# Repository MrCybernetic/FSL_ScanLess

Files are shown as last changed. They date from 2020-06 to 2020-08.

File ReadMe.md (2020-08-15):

Feel free to join the chat / N'hésite pas à venir discuter : 



# SCANLESS
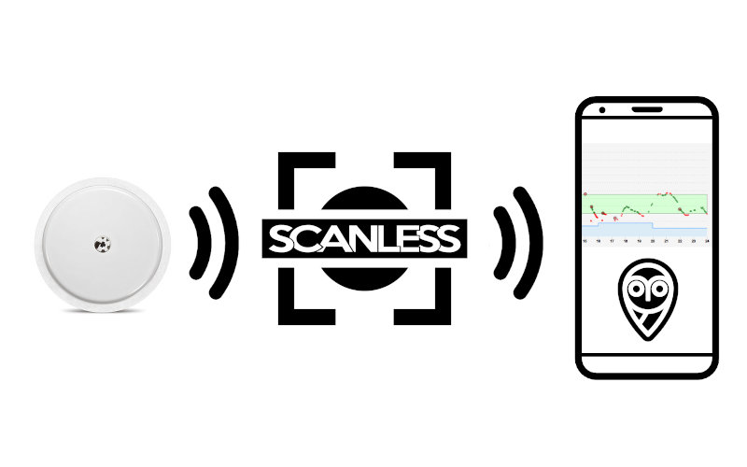
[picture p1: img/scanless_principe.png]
XDrip Principe
 

EN Flag EN

Designing an open source PCB to turn your Freestyle Libre into a wireless CGM (continuous glucose monitor) based on LimiTTer ([Limitter Original Project](https://github.com/JoernL/LimiTTer)). Hardware inside :
+ BM019 NFC tag reader ([BM019 from Solutions Cubed](http://www.solutions-cubed.com/bm019/), see BM019 folder to see documentation and schematics)
+ HM17 BLE Module
+ Atmega328P (Arduino Pro Mini compatible)
+ USB to Serial Converter to program the Arduino (CP2104)
+ LiPo Charger (MCP73831)
+ LiPo Battery (3.7V)

SCANLESS is an open source Project NOT maintained by Abbott. It is a experimental DIY project. You can contribute in this project as you want.

## Project Progress

+ BM019 tested  :heavy_check_mark: 
+ Electronics : Schematics and PCB reviewed :heavy_check_mark: 
+ BLE to test :heavy_check_mark:
+ Arduino to test ([Keencave Github / LBridge Arduino Code](https://github.com/keencave/LBridge)) :heavy_check_mark:
+ XDrip to test :heavy_check_mark:
+ Design 3D printable enclosure :heavy_check_mark:

--- 

FR Flag FR

Le but de ce projet est de concevoir un PCB en open source pour suivre votre glycémie via votre smartphone. Ce projet est basé sur celui-ci : LimiTTer ([JoernL Github / Projet Original Limitter](https://github.com/JoernL/LimiTTer)).
+ Lecteur de tag NFC BM019 ([BM019 de Solutions Cubed](http://www.solutions-cubed.com/bm019/), la doc du BM019 et son schéma est dans le dossier BM019)
+ module BLE HM17
+ Atmega328P (Compatible avec Arduino Pro Mini bootloader)
+ Convertisseur USB vers Série pour pouvoir programmer l'Arduino (CP2104)
+ circuit intégré pour charger la LiPo (MCP73831)
+ une batterie LiPo (3.7V, ???mAh pas encore définie)

SCANLESS est un projet open source non supporté par Abbott. C'est un projet DIY expérimental. N'hésitez surtout pas à proposer des améliorations.

# Avancement

+ Tester le fonctionnement du BM019 :heavy_check_mark:
+ Vérification des schémas électronique :heavy_check_mark: 
+ Tester le BLE :heavy_check_mark:
+ Tester le code Arduino ([Keencave Github / LBridge Arduino Code](https://github.com/keencave/LBridge)) :heavy_check_mark:
+ Tester l'appli XDrip :heavy_check_mark:
+ Concevoir une coque imprimable (3D) :heavy_check_mark:

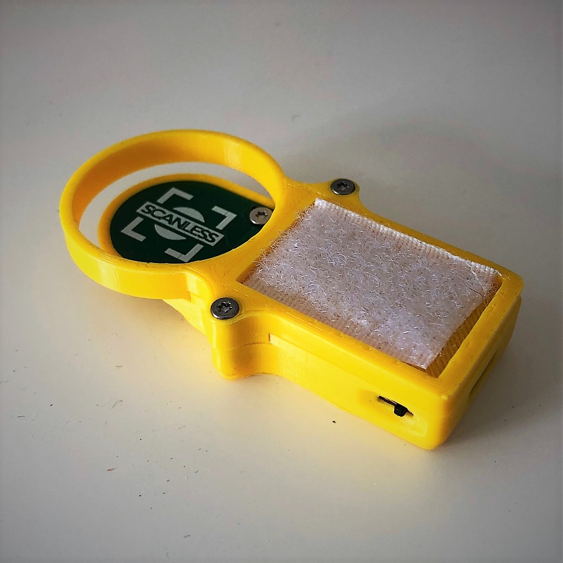
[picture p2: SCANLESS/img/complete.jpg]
PCB


*Actual state / état actuel*

# **#WeAreNotWaiting**

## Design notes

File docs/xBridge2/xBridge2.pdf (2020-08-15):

### XBridge2 - v2.48b (Use only with xDrip+)

XBridge2 is firmware code for a Pololu Wixel, and additional circuitry, that can make the wixel act as a bridge between a Dexcom G4 Transmitter and a smart phone using Bluetooth 4.0 (BLE) with HM-10/11 modules, or Bluetooth 4.1 with HM-16/17 modules. It requires that the Wixel be connected to a HM-1x BLE module, using the design originally put together by Stephen Black for his XDrip system as a minimum. There is a minor hardware modification required in order to receive the bridge battery voltage for monitoring in the app, and a modification to the wiring that allows the HM-1x to be powered down with the wixel low power mode, and powered up when the wixel wakes. Please see the Circuit diagrams below.

V2.48b adds support for packet caching, thanks to @savek-cc. This means that the bridge can store up to 5 hours of captured packets, and allows you to walk away from your phone running xDrip+. When you come back in range of the phone, and the next packet from the Dexcom transmitter is received, all of the saved packets will be sent to xDrip+.

NOTE: This wixel app can be used with a classic xDrip-wixel wiring, but you will not have the full battery saving features the code can provide. The xBridge2 code will automatically detect if you are using a classic xDrip-wixel circuit, and automatically detect your HM-1x module baud rate.

Acknowledgements
The original code, engineering and decoding of the Dexcom data packet was done by Adrien de Croy, whithout whom this project would not be possible.

The inspiration to continue came from Lorelei Lane, Jason Calabrese, and others of the Nightscout community and foundation.

The original XDrip circuit upon which this work is based was engineered by Stephen Black, who also created the XDrip app.

The battery monitoring circuit was designed by Chris Botelho.

The method of powering down and powering up the HM-10 module was engineered by Gabor Szakacs.

The method added in v2.47e that improves the BLE stability with Android Phones was inspired by the work of @keencave and @danpowell88 on the xDrip+ gitter room.

The Packet Cache capability was engineered by @savek-cc.

Also, I wish to acknowledge the work of “lumos” and “slasi” of the Pololu Wixel forum for their work in Sleeping the wixel and radio correctly. I have made copious use of “slasi”’s radio_mac library, and used some of the code in “lumos”’ sleep library in the xBridge wixel code.

Overview
As the name suggests, this device acts purely as a bridge between the Dexcom G4 Transmitter and a Bluetooth Low Energy capable device, such as a mobile phone or tablet.

It retransmits the data obtained from a Dexcom G4 transmitter packet. It DOES NOT ALTER OR RECALCULATE that data. It performs no math or translation of the raw data in the packet to an estimated Blood Glucose value.

It should be noted that only three pieces of data are retransmitted from the Dexcom G4. These are the two 32bit values representing blood glucose data, and an 8 bit value representing the battery condition in the G4 transmitter.

It adds information about the XBridge battery, as a percentage of remaining capacity, and the Dexcom G4 Transmitter ID that it is filtering on. Each Data packet also includes a 32bit Unsigned Integer value representing the number of milliseconds since the packet was captured by the bridge.

This device and software, and any companion software developed for use with it, MUST NOT be used for making therapeutic decisions about diabetes management. Always use your standard Blood Glucose devices and management strategies. This is for informational and experimental use only.

The original wixel code for XDrip was based on work by Adrien de Croy, Lorelai Lane, and others, but it has some limitations. This bridge code has the following features to address these:

- Does not receive any Dexcom packets until it has been given a Dexcom G4 Transmitter ID to filter on. This is important to ensure that it correctly locks on to the signal of the transmitter in question, and only passes that Transmitter ID’s data to the phone app. IMPLEMENTED (v2)
- Stores the Transmitter ID in flash, so that it survives if power fails for any reason. The app does not need to reset this in such an event. IMPLEMENTED (v1)
- Sends a “beacon” to the app when it wakes up from low power mode, indicating the Transmitter ID it is filtering on. The app can either send a TXID packet if the Transmitter ID the wixel should be filtering on is incorrect, or ignore the beacon. This is necessary to ensure that when a patient changes their transmitter, the app knows when the wixel is awake so it can be sent a new TXID packet. Normally, the wixel will wake up 5 minutes after the previous good packet and stay awake until it receives a packet from the Dexcom transmitter it is configured to filter on. IMPLEMENTED (v2)
- Sends a “beacon” to the app every 5 seconds if the code is newly installed and the wixel has NOT received a TXID packet. It will continue to send beacon packets at 5 second intervals until a TXID packet is received and the Dexcom transmitter ID is saved to flash. The beacon will indicate the ID to be zero, and the app, once configured with a Dexcom Transmitter ID, must send a TXID packet before the code will start accepting packets. The wixel will respond to the TXID packet with a “beacon” packet indicating the TXID that is set in flash on success. IMPLEMENTED (v2)
- Accepts a Transmitter ID packet from the phone app, and saves it to flash. Note, the phone app must await either a data packet or a beacon packet before determining if the Transmitter ID is incorrect, and sending a TXID packet to the bridge. IMPLEMENTED (v1)

- Sends the Bridge battery capacity percentage, determined from the battery voltage, as part of the data packet. IMPLEMENTED (v2)
- Automatically corrects the packet “listen window” for changes in overall program cycle time. This ensures that any changes to the code does not require any further experimentation to the listen window to make it work reliably. NOT YET IMPLEMENTED
- Sets the HM-10 module’s BLE ID to “XBridgeXX”, where XX is the least significant byte of the wixel serial number. This ensures that each bridge has a reasonably unique ID, making the BLE connection to the phone running the app more reliable. IMPLEMENTED (v2)
- Will not deep sleep if the wixel is connected to a PC USB port. This allows experimentation or re-scanning for the BLE device by an ap, if for any reason it is lost or the app is replaced, while the bridge has been programmed with a transmitter ID. It also allows for packet capture by a PC for analysis of performance. IMPLEMENTED (v2.1)

Version History
1 | Experimental and Proof of concept. Used to refine the Packet Capture code, develop flash storage of the Transmitter ID, and general operation of the wixel as a bridge device. Text only protocol and commands.
2 | Consumer ready version. All packets are retransmitted as binary packets. Implemented: • Wixel Power Mode 2 sleeping • Wixel Power Mode 1 on USB connected to PC. • Battery monitoring • HM-1x module power down • Protocol Functional Level 1
2.47e | Improved sleep coding for stability of timing between packets. Improved radio reception.
2.48b | Implemented Packet Cache for storing packets when not in range of a phone running xDrip+. NOTE: This version will NOT work with the classic xDrip app, which is deprecated.

Protocol
Each packet of data sent or received by the bridge is described below. Common to each packet are the first two 8bit bytes. The first byte is the length of the packet in bytes. The second is an ID for the type of packet being sent.

Note that packets sent from the bridge to a phone app will include a last byte representing the Protocol Functional Level that the wixel firmware is programmed to. This was requested by Stephen Black, and makes sense. If more protocol functionality is added in future, any app using the bridge will need to know how to deal with various versions of firmware/protocol level in the wixel.

Data Packet
A Data packet is sent by the wixel to the phone app. It contains the relevant data sent from the Dexcom G4 Transmitter, plus the bridge battery voltage and TxID it is filtering on.

The data packet has the following structure:

Byte | Value | Data Type | Description
0 | 0x11 | 8 bit unsigned integer | Number of bytes in the packet (17)
1 | 0x00 | 8 bit unsigned integer | Code for Data Packet
2:5 | Raw Signal | 32 bit unsigned integer | Raw Sensor signal
6:9 | Filtered Signal | | Filtered Sensor signal
10 | Dexcom Tx Battery Voltage | 8 bit unsigned integer | The Transmitter battery voltage. Usually around 214 for a new transmitter. The app should alert if this reaches <= 207, that the transmitter requires replacement.
11 | Bridge Battery Percentage | 8 bit unsigned integer | The bridge battery percentage (0-100). This is calculated from the VIN voltage using a 10k/27k resistive voltage divider on P0_0. VIN of 3.2V (equivalent to 865mV input on P0_0) is 0%, as this is the lowest operating voltage of the battery. VIN of 4V (equivalent to 1081mV input on P0_0) is 100%, as this is the maximum voltage delivered the battery stably returns to once power is removed from the battery.
12:15 | Dexcom TxID | 32 bit unsigned integer | Encoded Dexcom Transmitter ID that the bridge is filtering on.
| ms Ago | 32 bit unsigned integer | Number of miliseconds since the packet was received.
16 | XBridge Protocol Level | 8 bit unsigned integer | XBridge protocol level. Indicates the protocol level of xBridge. Note, that currently this will be 0x01.

Upon receiving this packet, the phone app has to process it, taking the parts of the packet it will use.

If the app determines that the Dexcom TxID is different to its own setting, it should immediately send a TXID packet back to the bridge, and ignore the packet.

If the app is happy with the Dexcom TxID sent, it should accept the packet and immediately send back an acknowledgement packet. The acknowledgement packet will tell the wixel to send the next pending packet from the Packet Cache. If there are no pending packets, it tells the wixel to go into low power mode.

The acknowledgement packet structure is as follows:

Byte | Value | Data Type | Description
0 | 0x02 | 8 bit unsigned integer | Number of bytes in the packet (2)
1 | 0xF0 | 8 bit unsigned integer | Code for Data Packet
This packet does not include indication of the XBridge protocol functional level, as it is from app to bridge.

Note that the wixel will otherwise go into low power mode if it does not receive an acknowledgement or TXID packet within 2 minutes of transmitting a data packet.

Both the Data Packet and Acknowledgement packet are part of Protocol Functional Level 1 (0x01)

TXID packet
The TXID packet is sent from the phone app to the bridge to set the bridge to filter on a single Dexcom G4 transmitter ID. This is important to ensure the bridge correctly “locks” to the correct transmitter for a patient, and also to ensure the app only receives packets from the transmitter of the patient it is monitoring.

The structure of the TXID packet is as follows:

Byte | Value | Data Type | Description
0 | 0x06 | 8 bit unsigned integer | Number of bytes in the packet (6).
1 | 0x01 | 8 bit unsigned integer | Code for Data Packet
2:5 | TxID | 32 bit unsigned integer | Encoded 32 bit integer representing the Dexcom G4 Transmitter ID that the bridge is filtering packets on.

Note: as this packet is sent from the app to the phone, it does not include a XBridge protocol level byte.

The TXID packet is part of Protocol Functional Level 1, although the app does not send this byte tag to the bridge device.

Beacon packet
The Beacon packet is sent from the bridge to the phone app to indicate which Dexcom G4 Transmitter ID it is filtering on. The app can use this beacon to know when the bridge is active, and if it has a different Transmitter ID to what the app is configured for, it can correct this by sending a TXID packet.

The structure of the Beacon packet is as follows:

Byte | Value | Data Type | Description
0 | 0x07 | 8 bit unsigned integer | Number of bytes in the packet (6).
1 | 0xF1 | 8 bit unsigned integer | Code for Data Packet
2:5 | TxID | 32 bit unsigned integer | Encoded 32 bit integer representing the Dexcom G4 Transmitter ID that the bridge should filter packets on.
6 | XBridge Protocol | 8 bit unsigned integer | XBridge protocol level. Indicates the

Level | protocol level of xBridge. Note, that currently this will be 0x01.

Note, this packet also doubles as the acknowledgement packet for a TXID packet. When the app receives this packet it can be sure that this is the Transmitter ID value set in the wixel flash memory.

The Beacon packet is part of Protocol Functional Level 1.

### Decoding and Encoding a Transmitter ID Long Int

In order for the app to send the correct value in a TXID packet to the bridge, you need to be able to encode the text of the Transmitter ID to a long int. This is done using the following pseudo code, taken directly from the original xBridge code. Your app will need to replicate this process in order to send the correct data.

char SrcNameTable[32] = { '0', '1', '2', '3', '4', '5', '6', '7', '8', '9', 'A', 'B', 'C', 'D', 'E', 'F', 'G', 'H', 'J', 'K', 'L', 'M', 'N', 'P', 'Q', 'R', 'S', 'T', 'U', 'W', 'X', 'Y' };

/* asciiToDexcomSrc - function to convert a 5 character string into a unit32 that equals a Dexcom transmitter Source address. The 5 character string is equivalent to the characters printed on the transmitter, and entered into a receiver.
Parameters:
addr - | a 5 character string. eg "63GEA"
Returns:
uint32- a value equivalent to the incodeded Dexcom Transmitter address.
Uses:
getSrcValue(char)
This function returns a value equivalent to the character for encoding.
See srcNameTable[]
*/
uint32 asciiToDexcomSrc(char addr[6])
{
// prepare a uint32 variable for our return value
uint32 src = 0;
// look up the first character, and shift it 20 bits left. src |= (getSrcValue(addr[0]) << 20);
// look up the second character, and shift it 15 bits left. src |= (getSrcValue(addr[1]) << 15);
// look up the third character, and shift it 10 bits left. src |= (getSrcValue(addr[2]) << 10);
// look up the fourth character, and shift it 50 bits left. src |= (getSrcValue(addr[3]) << 5);
// look up the fifth character
src |= getSrcValue(addr[4]);
//printf("asciiToDexcomSrc: val=%u, src=%u\r\n", val, src); return src;

}

/* getSrcValue | - | function to determine the encoding value of a
character in a Dexcom Transmitter ID.
Parameters:
srcVal | - | The character to determine the value of
Returns:
uint32 | - | The encoding value of the character.
*/
uint32 getSrcValue(char srcVal)
{
uint8 i = 0;
for(i = 0; i < 32; i++)
{
if (SrcNameTable[i]==srcVal) break; }
//printf("getSrcVal: %c %u\r\n",srcVal, i); return i & 0xFF;
}

Decoding a long integer transmitter ID is far simpler. You may implement a similar piece of code if you are storing the ID as a long int, but wish to display the text equivalent.

// convert the passed uint32 Dexcom source address into an ascii string in the passed char addr[6] array.
void dexcom_src_to_ascii(uint32 src, char addr[6])
{
//each src value is 5 bits long, and is converted in this way.
addr[0] = SrcNameTable[(src >> 20) & 0x1F]; | //the last
character is the src, shifted right 20 places, ANDED with 0x1F
addr[1] = SrcNameTable[(src >> 15) & 0x1F]; | //etc
addr[2] = SrcNameTable[(src >> 10) & 0x1F]; | //etc
addr[3] = SrcNameTable[(src >> 5) & 0x1F]; | //etc
addr[4] = SrcNameTable[(src >> 0) & 0x1F]; | //etc
addr[5] = 0; | //end the string with a null character.
}

### Note on Promiscuous mode

In this code, if the wixel is NOT sent a TXID packet, it will NOT collect packets from any Dexcom Transmitter and pass them to the smartphone app. This is a safety feature and is by design. You do not want an app displaying or storing data from anyone else’s transmitter.

However, in the part of the code that collects packets, promiscuous mode is allowed.

If you really wish to use promiscuous mode, first set an initial transmitter ID in the app. Once it has been received by the bridge, set the transmitter ID to “00000”. Once the wixel accepts this packet, it will receive an initial packet from a transmitter, and will then by “time locked” to that transmitter.

Note that until I get channel scanning mode working correctly, “promiscuous mode” will not necessarily show all packets from all transmitters in range. It is therefore not a true “promiscuous mode”.

### Basic code operations

The Wixel code uses the following steps when it wakes up or is powered on. This information is important to help you determine a cause if something is not working as you expect.

- Initialises all the base IO and Wixel systems.
- Waits for 30 seconds, processing IO. This allows you to connect a serial terminal to it via USB, so you can see what is going on.
- Loads the internal Flash stored flags register to determine if it has set up the HM-1x module. It only does this the first time it is run after the XBridge code is loaded. No point doing it too often.
- If the flag shows that the HM-1x is NOT configured, it will configure it.
- Loads the Battery Capacity limits from Flash. If these are not set up, it sets them to default values.
- Loads the TXID value from Flash, if it exists.
- Powers up the HM-1x module.
- If the TXID value is NOT set, it goes into a loop, waiting for a BLE connection, and then sends Beacon packets until it gets a TXID packet. It then stores all the settings to flash, and moves on.
- Goes into a loop where it listens for Dexcom Transmitter packet.
- If a Dexcom Transmitter packet is not received in 320 seconds (5 minutes 20 seconds), it sends another beacon packet and tries again. The Wixel will NOT sleep until it has captured an initial packet from the Dexcom G4 transmitter.
- Once it has captured a packet, it stores the packet in the Packet Cache and waits for a BLE connection to be established between the HM-1x and the phone. It then sends each pending Data packet from the Packet Cache.
- If an ACK packet is not received in 10 seconds, it resends the Data packet.
- If an ACK is received, it sends the next pending packet from the Packet Cache. If no packets are pending, it saves all the settings back to flash, turns off the HM-1x module, sets all its IO to low to save power, and goes to sleep for around 240 seconds.
- Upon waking from sleep, it repowers the HM-1x, restarts it’s radio, and begins waiting for packets again.
- At any point in time, a packet from the app or a packet or command from the USB can be received. It is processed immediately, and the program returns to where it last was.

### Basic flow of communications

From start up after code is loaded on the wixel, the xBridge2 code will begin sending Beacon Packets at 5 second intervals on UART1 and USB (if it is connected). To break this cycle, a TXID packet must be received on either UART1 or USB (if connected).

Once the wixel has received a TXID Packet and saved the info to flash, it will begin scanning for Dexcom packets from that transmitter.

When the wixel receives a Dexcom data packet, it will send a Data Packet on UART1 or USB (if connected).

The receiving app must process the packet, and if the TXID sent in the packet is valid, it may send back a data ACK packet, which will immediately send the wixel to sleep for a period of time until before the next packet is due.

If the TXID in the data packet is incorrect, the app must send back a TXID packet to the wixel to set it to the correct ID.

The wixel will send a Beacon Packet, if it has not received a Data Packet within 5 minutes and 30 seconds of waking. The app must process this packet, and ignore the beacon packet if all is good, or send a TXID packet if the beacon contains the wrong ID. This ensures that when a patient changes their transmitter ID in the app, the wixel can be updated as soon as possible after it wakes, and before it receives a packet from the new transmitter. If no beacon was sent when the wixel woke, the wixel would simply loop indefinitely until it received a packet from a transmitter that was no longer functioning.

The reason that we have had to send beacons this way is for two reasons. First, the BLE implementation in Android does NOT cleanly detect a closed connection, and retry connection at a fast enough rate to guarantee that it will connect immediately the HM-1x module is powered on by the Wixel. Otherwise, we would send the beacon as soon as the Wixel wakes and powers the HM-10 on. Any delay between wake and beginning packet capture could prevent a dexcom packet being missed.

Secondly, we do not want to interrupt the packet capture, so it is best to set a limit on packet capture, stop and send the beacon, and then start packet capture again. So, allowing packet capture to run a little longer than the anticipated 5 minutes means we are less likely to miss a packet capture.

### Parts List

The minimum parts required to make a working xBridge circuit are:

1x Pololu Wixel

1x Adafruit Micro Lipo Charger with Micro USB Jack (PRODUCT ID: 1904) or equivalent.

1x 10k 1% 1/2W metal film resistor.

1x 27k 1% 1/2W metal film resistor

1x JNHuaMao HM-1X (HM-10/HM-11 with CC2541 SoC, or HM-16/HM-17) based BLE module.
Note: If you are ordering a HM-10/11, make sure you are getting a CC2541 SoC and NOT a CC254 SoC. JNHuaMao are no longer releasing firmware for the CC2540 SoC.
Note: If you are ordering a HM-16/17 module, make sure you specify the minimum firmware version of v119. There is currently no way you can update the firmware on the HM-16/17 modules yourself.

Either 1x 10uF and 1x 0.1uF capacitor, or a single 11uF capacitor ONLY if you are using a HM-16/17 module. This is not required for HM-10/11.

1x 3.7V Lithium Polymer (LiPo) battery. The capacity is your choice, but recommend 1200mAh for 5 days or more continuous operation without a recharge. This should come with a JST connecter already fitted, which plugs into the JST socket on the charger board.

As a guideline to how long you can expect a particular battery to last, use the formula below. Note this is theoretical only, do not expect this full figure to be achieved. This formula is for comparison of battery capacities only, and only applies to xBridge2 circuit and wixel firmware.

Days Life = (Battery Capacity mAh/7)/24

So for a 1200mAh battery, Days Life = (1200/7)/24 = 7.14

Optionally you can include:

20mm Reverse/Forward Micro USB Qi Universal receiver Module (Adafruit Product IDs 2114, or 2116. This plugs into the charger board micro USB jack.

Switch in the Battery Positive lead to turn ON/OFF the bridge.

JST Plug with wire, and Socket. Solder the socket to GND and VIN (Make sure the polarity is correct, Red battery wire goes to VIN, Black goes to GND), and solder the JST Plug and Wire to the output pins of the charger board. You can then easily disconnect the wixel from the battery and charger board when not using the bridge.

### Circuit diagrams

Bare HM-10 or HM-16 connected to Wixel and Adafruit charger board.

10k

27k

Resistors are 1% 1/2W metal film

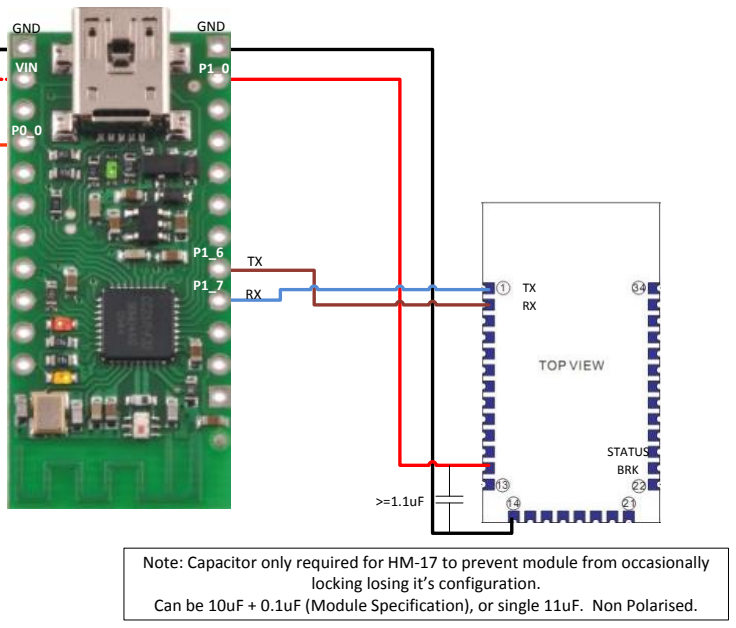
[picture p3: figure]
BRK; GND P1_0 GND; VIN

STATUS >=1.1uF Note: Capacitor only required for HM-17 to prevent module from occasionally locking losing it’s configuration. Can be 10uF + 0.1uF (Module Specification), or single 11uF. Non Polarised. Note: be VERY careful not to overheat the solder pads on the HM-10 module. They are

rather fragile. Also ensure that your wires do not place undue pressure on these.

HM-10 on support board, with Wixel and Adafruit charger board.

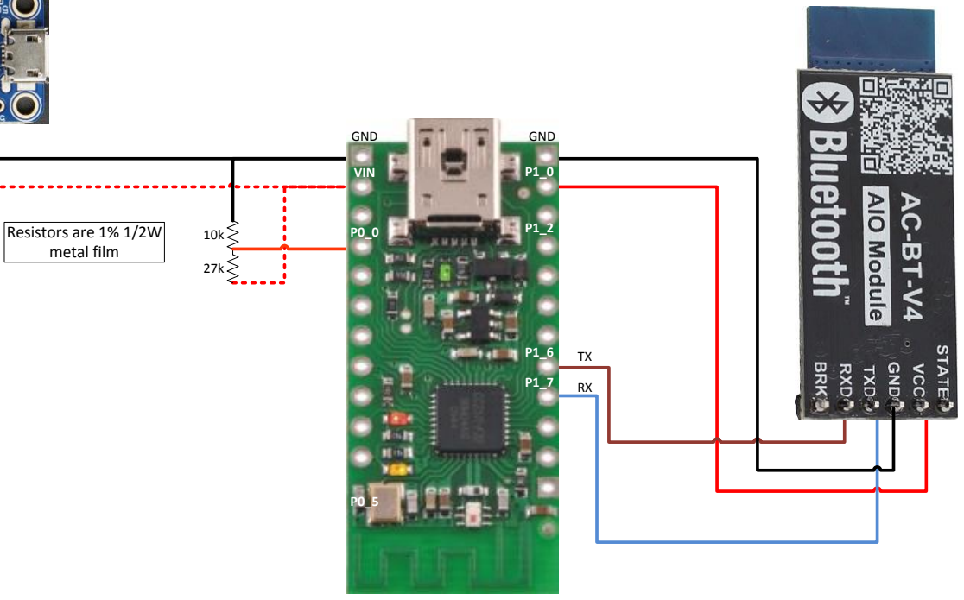
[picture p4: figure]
GND; P1_0 GND; VIN; Resistors are 1% 1/2W metal film

Bare HM-11or HM-17 board

10k

27k

RX

TX | BRK

Resistors are 1% 1/2W metal film

STATUS

VCC

UART_TX UART_RX | GND

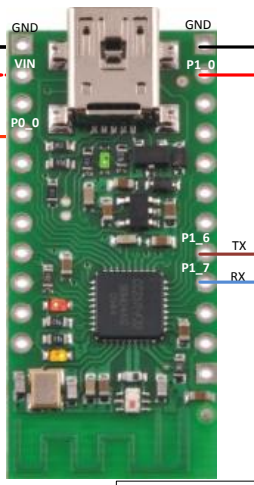
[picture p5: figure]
GND P1_0 GND; VIN

>=1.1uF Note: Capacitor only required for HM-17 to prevent module from occasionally locking losing it’s configuration. Can be 10uF + 0.1uF (Module Specification), or single 11uF. Non Polarised.

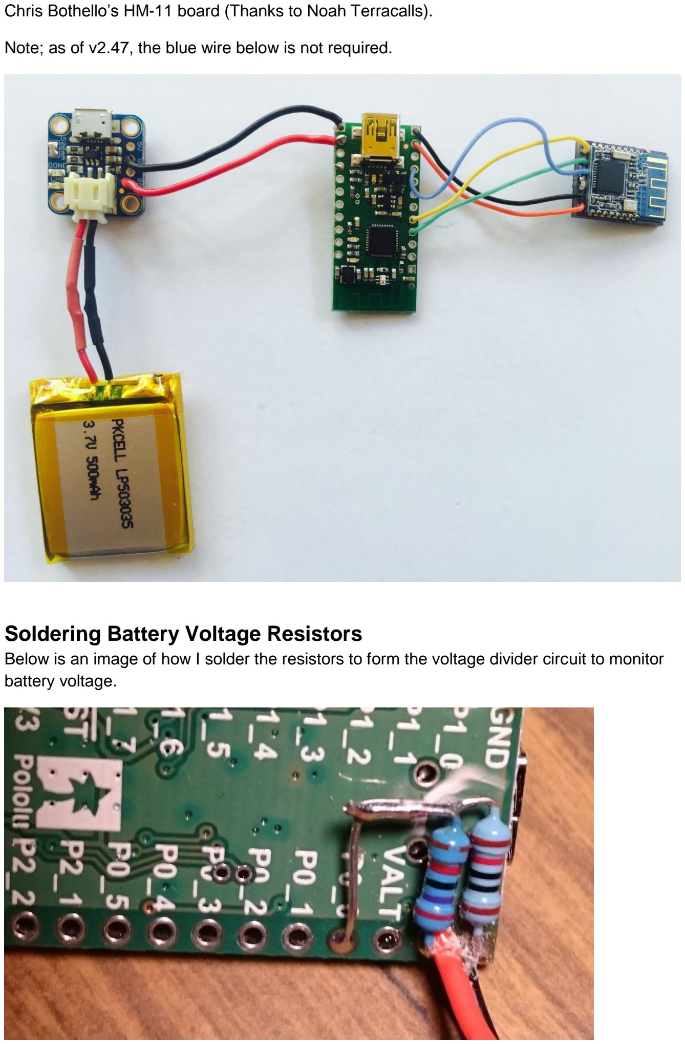
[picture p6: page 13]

Chris Bothello’s HM-11 board (Thanks to Noah Terracalls).

Note; as of v2.47, the blue wire below is not required.

### Soldering Battery Voltage Resistors

Below is an image of how I solder the resistors to form the voltage divider circuit to monitor battery voltage.

### Options for Charging

Note that it is DANGEROUS to allow a LiPo battery to drop below it’s minimum voltage for any length of time. They do include cut out circuitry to prevent this, but they still continue to discharge over time. Always keep your LiPo charged.

The most obvious way to charge the bridge battery is to connect the Adafruit charger board to a micro USB cable and plug it in to a USB port. Once the Red LED goes out and the Green one comes on, the battery is charged.

However, this is not always convenient, especially if you want a somewhat waterproof bridge. You need to open the case, and connect things.

Something that has been used quite a bit is a Qi charger pad. Qi is a Near Field Wireless charging standard used in Mobile phones etc. Adafruit (and their resellers) have a number of these receiver pads, but you will want to get either of the models that have micro USB connectors on them. You plug these in to the Adafruit charger board, and place the charger receiver pad flat on the inside of one side of the bridge box you are using. You can then place it on a Qi transmitter charger pad (available in lots of places for $20-$50 USD), which commonly connects to a USB power supply of some sort.

Once placed on the Qi transmitter charger pad, the Red charger LED should light in the bridge. You may need to move it around a bit to make sure the centre of the receiver pad is over the centre of the transmitter pad. And that really is the only issue with the wireless charging, that it can be easily knocked and the charging mistakenly interrupted.

The choice is entirely yours.

### Updating the HM-10/11 module firmware

NOTE WELL: Seed Studio (www.seedstudio.com) and some other suppliers are distributing HM-11 modules that are NOT genuine, and therefore this procedure will not work with those modules. A genuine HM-11 module will respond to an
AT+NAME? command with “OK+NAMEHMSoft”, and will also advertise itself on BLE as “HMSoft”. If your module does NOT respond with this name, or advertise itself with this name, it is not genuine. However, it may still function just fine with xBridge2 wixel app, as the app will automatically detect the baud rate of the module and use it.

If you wish to be sure you have a genuine HM-11 module, I recommend ordering from https://www.fasttech.com/product/1740900-hm-11-bluetooth-v4-0-transceiver-ble-module. (https://www.fasttech.com/product/1740900-hm-11-bluetooth-v4-0-transceiver-ble-module) I have found this supplier to be reliable and responsive.

Also note:

There is no new firmware for the HM-10/11 boards running a CC2540 SoC. Specify the CC2541 SoC when ordering a HM-10/11 module.

The firmware on HM-16/17 modules cannot be updated. Specify the minimum version V119 when ordering, and return the module if you do not get it.

In order to ensure consistent operation of XBridge and the HM-1x modules, it is recommended that once you assemble the hardware, you immediately update the firmware of the HM-1x module you are using. This is necessary, because they are often delivered with one of two SoC devices (cc2540 or cc2541), and various levels of firmware depending on the source.

To rectify this, upgrade to at least level V534. This is the level that the wixel code for XBridge has been tested against. Note: as long as your module responds to an AT command with OK, it will work fine with xBridge2.

Prerequisites
Firstly, you will need to either obtain the compiled usb_serial.wxl file (can be found at https://github.com/jstevensog/wixel-sdk/blob/master/apps/usb_serial/usb_serial.wxl), or compile it using the wixel-sdk located at https://github.com/jstevensog/wixel-sdk. Connect your wixel to a computer via USB, and use the Wixel Configuration Utility to load this onto your wixel.

Secondly, you will need a terminal program. There are two options here. Either use a standard serial terminal program (PuTTY, Hyperterminal, etc) or an Arduino terminal program. The Arduino terminal program is probably the preferred option, but a standard serial terminal program can be used, it is just slightly more fiddly. Try the JNHuaMao PC Comm Assistant located at http://www.jnhuamao.com/HMPCComAssistant_en.rar, or if you are on Windows 10, either http://www.jnhuamao.com/HMBLEComAssistant_x86.zip or http://www.jnhuamao.com/HMBLEComAssistant_x64.zip depending on if you are using 32 or 64 Bit windows.

When using a standard terminal program, like PuTTY, you will need to PASTE the command into the terminal window. This is because the HM-1x modules DO NOT accept a CR or LF character. They only detect a delay at the end of the command string and try to execute it. If you try to type the command into the terminal program, it will ignore you as you cannot type quickly enough to get the whole command in.

Note: Set the terminal parameters to be 9600 baud, 8 bits, 1 stop bit, no parity.

Some people have reported receiving HM-1x modules that use a different baud rate (115200). However, the JNHuaMao documentation states that the default baud rate for the HM-10 and HM-11 modules is 9600 baud. As pointed out above, the module you receive may not have the latest firmware on it, and may not have been reset post Quality Assurance testing and being delivered to you. Once you have loaded the latest firmware on to your module, it SHOULD then be communicating at 9600 baud. If it is still not communicating at this baud rate, you will need to issue the command “AT+BAUD0” followed by “AT+RESET”, and confirming that the module is now communicating at 9600 baud, prior to loading the xBridge2 app onto the wixel.

Thirdly, go to http://www.jnhuamao.cn/download_rom_en.asp?id=# and download the V534 firmware zip file that is correct for the SoC on your HM-1X device. Use a magnifying glass to read the model number on your module. It should be either CC2540 or CC2541. If you are going to be making a few of these bridges, download both. You never know which one you are going to get. Unzip the contents into a folder. You will have a readme.txt file, a HMSoft.bin file (the firmware), and a HMSoft.exe file (the firmware updating utility).

Updating steps.
1. Ensure you have the wixel attached to a PC via USB.
2. Ensure you know what COM port it is represented as. You can use the Wixel Configuration Utility to find this out.
3. Ensure you have installed the usb_serial.wxl program on the wixel.
4. Open your terminal program.
5. Send “AT” to the wixel. The response should be “OK”.
6. Send “AT+SBLUP” to the wixel. It will respond with “OK+SBLUP”. It is now ready and waiting to accept the firmware update.

### 7. SHUT DOWN YOUR TERMINAL PROGRAM NOW!!!!!

8. Open the HMSoft.exe file. It will open a window like this.

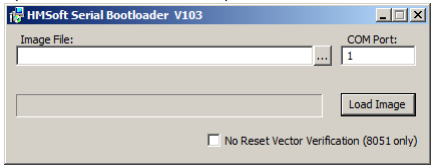
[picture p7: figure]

9. Click on the button to the right of the “Image File:” text box to navigate to the image file. Below is an example.

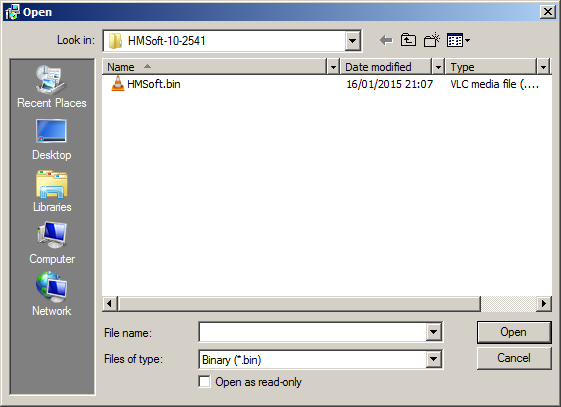
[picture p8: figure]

10. Enter the COM port number. For example, my wixel in this case is on COM 10, so my window will look like this.

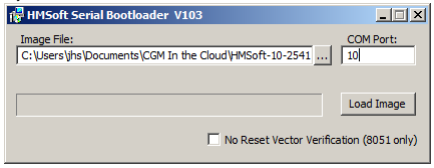
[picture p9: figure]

11. Click the “Load Image” button. The progress bar will show the progress. The process takes a few minutes to complete. Once it has finished, the HM-1x module will be updated to the required level. Close the firmware update (HMSoft Serial Bootloader) window.
12. To verify the Firmware level of the module, open your terminal program once again. Send the command “AT+VERR?”. You will see a response like “OK:HMSoft v534”
13. That is it. You can now load the xBridge2.wxl file using the Wixel Configuration Utility, and the bridge is ready for use.

Modifications to use xBridge app with the xDrip-wixel circuit.
The xBridge2 firmware now automatically detects if the circuit is wired as a “classic” xDrip wixel or an xBridge when it is powered on. It will automatically configure itself to use the original Chris Bothello voltage divider resistors if it detects a classic circuit, so it can pass the battery capacity on to xDrip.

If you do run xBridge2 on a classic circuit, you MUST select xBridge as your Data Collection Method in xDrip/xDrip+, otherwise it will not work.

The xDrip app can be configured to NOT display the bridge battery and pass it on to the Pebble watch face if you do not have the voltage divider resistors configured, or if you power the bridge from some other method (like directly wired to a phone as some have done).

Building the xBridge wixel program.
To build the xBridge wixel program, please use the Wixel SDK located at https://github.com/jstevensog/wixel-sdk. This SDK has both “lumos” sleep library and “slasi” modified radio_mac library. Although the code does NOT use the sleep library, it does use the radio_mac library.

Please see the instructions provided by Pololu to build the program if you are not familiar with how to do it.

Or, you can obtain the xBridge2.wxl file from that repository in apps/xBridge2 (https://github.com/jstevensog/wixel-sdk/blob/master/apps/xBridge2/xBridge2.wxl), and simply load that onto the Wixel using the Wixel Configuration Utility.

### Installing the xBridge app on the Wixel

Before you install the xBridge app on the Wixel make sure ALL phones or other BLE “master” devices within the vicinity are TURNED OFF (or at least Bluetooth is). Failure to do this will prevent the HM-1x module from being correctly configured IF another device has established a connection to it before the xBridge app has started and attempted to configure it.

The xBridge app currently waits for 30 seconds before starting so that, if you so desire, you can connect to it using a USB cable and serial terminal to watch the process of boot up.

Open the Wixel configuration utility, then open the xBridge2 app. Connect your bridge to your computer via USB. It should appear in the Wixel Configuration utility like this:

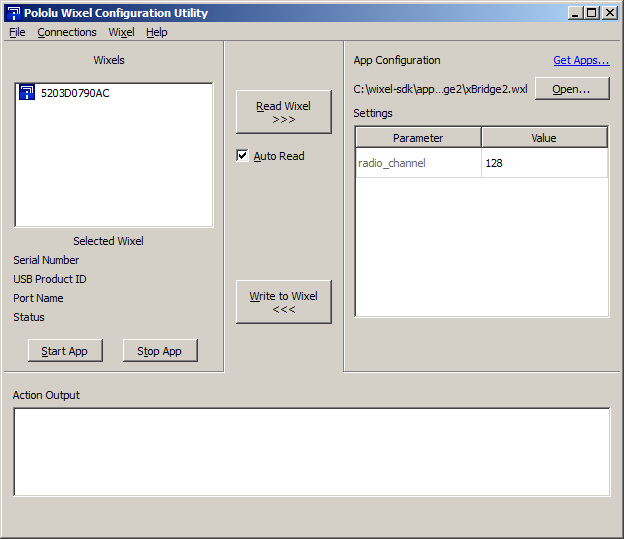
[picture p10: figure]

Click the Write to Wixel button, and the app will be loaded onto the wixel.

Wait for at least 30 seconds, until you see the Green LED on the wixel, and at least one blink of the Red LED. Or you can use a serial terminal to watch the boot process.

You should then be able to turn on your phone’s Bluetooth and scan for your xBridge using xDrip/xDrip+. You are looking for a name like “xBridgeXXYY”, where XX and YY are alpha numeric characters. Once you locate this device name, select it and a connection to your xBridge will be established.

If you see only a device called HMSoft, first try power cycling the wixel. If this does not work, there is an issue with the serial connection between the Wixel and the HM-1x. See the trouble shooting section.

The flashing (very fast and dim, every 10 seconds) Red LED is showing you that the wixel is trying to obtain a Transmitter ID. By default xDrip/xDrip+ has this set to “00000”. You need to configure xDrip/xDrip+ correctly to work with xBridge.

In xDrip/xDrip+ settings, select “xBridge Wixel” as the data source (the default is “xDrip Wixel”). Once you do this, a new setting will appear named “Dexcom Transmitter ID”. Select this setting and enter your Dexcom Transmitter ID. Remember to enter any letters (A-Z) as UPPER case.

There will also be a setting appear that allows you to Display (or Not Display) the bridge battery in xDrip/xDrip+. The default is to display this.

You should now be able to start your sensor, allow xDrip/xDrip+ to capture at least two packets, and do a double calibration to start using the system.

### Serial Terminal Commands

xBridge2 supports three commands you can issue on a serial terminal connected to the wixel via USB.

Note: The wixel MUST be awake for you to issue these commands. The best way to ensure this is the case, is to power cycle your wixel, as it will stay awake until it captures a packet from the Dexcom transmitter. Otherwise, wait until the HM-1x Status LED is blinking or solid, which indicates the wixel is awake. This will only hold true with an xBridge circuit.

When the wixel is power cycled, you have 10 seconds to connect a serial terminal before it goes into operation. Attempting to connect a serial terminal to a sleeping wixel will fail. Try again until you succeed, if you cannot power cycle the wixel.

S - Pressing the S key will provide you with a status display. This is useful in troubleshooting to let you know how xBridge2 thinks it is configured.

D – Pressing the D key will toggle (turn on or off the debug output) on the USB serial line. You will not need to do this unless you are experimenting with using an xBridge2 with a serial/USB program or device, that may be being confused bridy the debug output. Of course, if you are following the protocol description, this should not be necessary. However, if you are using a PERL SerialIO library, that expects either a line end or time delay parameter, you cannot effectively do a byte-by-byte capture of the stream and look for the identifying bytes for each packet type. In this case, this command may be of use.

B – Pressing the B key will toggle “sleeping” (powering down) of the HM-1x module on and off. It will display a message saying if it is on or off. This will assist those with phones or Android versions that do not reliably reconnect to the BLE device once it is powered on. If you experience lots of Bluetooth issues, or packet loss, you can use this command to prevent the HM-1x module from being powered down, and this should then resolve the issue. NOTE: This will impact your bridge battery life.

L – Pressing the L key will toggle the display of LEDs. Turning off LEDs will give you extra battery life. If you are satisfied that you can trust all is well with your bridge, you can turn LEDs off. The most affected by this is the Yellow BLE Connection State LED on the wixel. Otherwise known as “The Blazing Sun”. You might get a better night’s sleep with this off.

The wixel LEDs indicate as follows:

GREEN ON | Only shows if the wixel is connected to a computer via the USB port, AND a terminal program has connected to it.
RED Blinking 3 times, off, then repeating | The xBridge2 firmware has loaded, and is waiting for a TXID packet from the app (xDrip/xDrip+ or whatever).
RED Led constantly blinking at 1 second intervals | The xBridge2 has received a TXID packet, and is scanning for a packet from the Dexcom G4 transmitter.
YELLOW LED on | The HM-1x and the phone have established a BLE connection.

P – Pressing the P key will reset the battery capacity high and low voltage levels to defaults. Use this only when your battery capacity indication in xDrip/xDrip+ has become inaccurate. This will save you having to re-flash the wixel to correct this. Whilst I have never experienced this issue myself, with various wixels and bridges, some have reported that their battery indications become very inaccurate (they are merely an indication at best in any case).

### Problem Solving

Obviously, the first thing to check is the wiring between the component boards. Make sure all of this is correct before you go any further. Also, if you are experiencing issues with the battery capacity indication in xDrip/xDrip+, check that there are no dry joints or chances of a short circuit in the Voltage Divider resistor circuit.

Problems with updating the HM-1x firmware
These modules are fairly robust and can put up with a lot. If you for some reason happen to power down the module during firmware update, after you had entered the AT+SBLUP command, do not be alarmed. It won’t have completed the update process. Simply repower he module, and send the firmware file again. It will complete the process.

The most common problem with this, is establishing the connection with the module using usb_serial app on the wixel. It has been reported (though I have not seen it) that some modules are being delivered fixed to a different baud rate from that specified by the manufacturer as the default. You can determine what the baud rate is by setting your terminal program to different baud rates and issuing an “AT” on each until you get “OK” in response. Once you flash the new firmware onto the module, it should use the default 9600 baud rate, which is also used by xBridge.

BLE Name stays at HMSoft, instead of xBridgeXXYY.
If, when you scan for your xBridge in xDrip/xDrip+ (or any BLE scanner) you see the name HMSoft, this generally means one of two things:
1. You had a BLE connection established when you loaded the App onto the wixel. Disconnect your BLE module (even better, turn off all Bluetooth on any nearby phones), and re-flash the wixel code.
2. You did not verify that the HM-1x module is communicating at 9600 baud.
Either you did not update the firmware, or you simply didn’t check that this was the case. Re-load the usb_serial app onto the wixel, and determine the current baud rate by cycling from 115200 down. Once you determine the baud rate, reflash the new firmware onto the HM-1x module, or at the very least send the command “AT+BAUD0”, followed by “AT+RESET”.

How do I know if it is working?
Well, before you connect it to xDrip/xDrip+ or any other app, the wixel will wake. If you are not connected to it via a USB cable, with a serial terminal program, and for at least 30 seconds initially, you will not notice anything

After 30 seconds, you should see the GREEN LED light up if you are connected to USB and have a serial terminal program open to the port.

Because the code only turns on the Yellow LED when a BLE connection is made under normal operation, it is sometimes difficult to know what it is up to. Here are the steps to go through.

1. When you first load the xBridge2.wxl file onto the wixel and you are connected via USB, the GREEN LED will light after 30 seconds, and the RED LED will also light briefly at that point. The GREEN LED indicates it is connected to the USB port, and the RED LED indicates that it has read it’s settings from the FLASH memory.
2. Use a BLE utility, or xDrip/xDrip+, to scan for a BT device. You should find a device with a name like XBridgeXX. If you see that, the wixel has woken and correctly configured the HM-10 module, and should be ready to go.
3. If instead you see only a device called HMSoft, the wixel has not been able to correctly communicate with the HM-10 module. Check your wiring. And also check that you have loaded the xBridge2.wxl file on the wixel.
4. If you establish a BLE connection to the bridge, the green LED on the HM-1x module will go on, and the YELLOW LED on the Wixel will go on shortly after. This shows that the wixel is aware of the connection.
5. If you have not yet entered your Transmitter ID in xDrip/xDrip+, you will notice the RED LED will blink 4 times every 10 seconds. This is showing you that the wixel is telling xDrip/xDrip+ it doesn’t have a Transmitter ID to work with yet.
6. If you have entered your Transmitter ID in xDrip/xDrip+, and the bridge has not yet received a packet, the RED LED will blink (about ½ second on and off) while it is waiting for a packet from the transmitter.

NOTE: If you have used the L command on a USB terminal to toggle LEDs off NO LEDs will light as described above.

7. If you would like to see more of what is going on, connect the wixel with a mini USB cable to a PC or laptop. After a time (up to 5 minutes if it was sleeping when you connected), the Green LED will light. Connect a terminal program to the device. The wixel WILL SLEEP while connected to the terminal program, but only to a mode that allows the USB to remain open, if it has received a Dexcom Transmitter Packet, sent it, and received an ACK packet from the app.
8. If you would like to see the communications it is sending, you can open a serial terminal and connect to the wixel. Use 9600, 8, 1, no parity as the settings of the terminal. Note, that XBridge can send output that is NOT in text, so on occasion you will see silly characters. But you will also see a lot of diagnostic messages telling you what is going on. You can also send an “s” or an “S” from the terminal and you will get a Status message, detailing the contents of the Flash storage variables, and the variables that hold these values in the program. See below for details of the types of messages.

Example Output on USB Serial Port

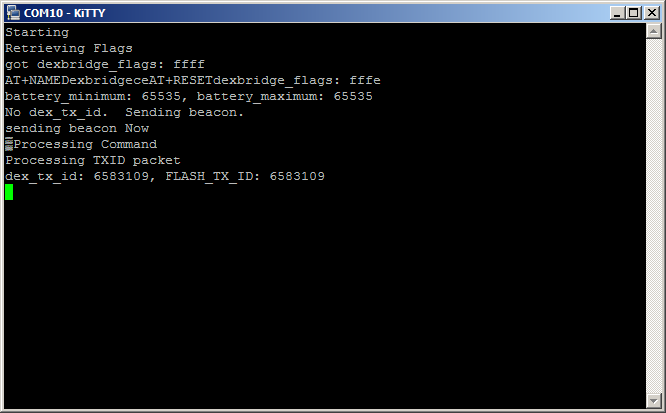
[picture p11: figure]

The screen shot above shows a boot up after the firmware is loaded. Note, that this wixel was already joined to an xDrip/xDrip+ app. As you can see, when it first started up, all the xBridge_flags were set to 1 (ffff). After the HM-1x was set and configured, the flags are now set to fffe. Also, the battery_minimum and battery_maximum settings are not yet set (showing 65535).

After it has configured the HM-1x it sends a beacon packet until it gets a TXID packet in response. Once it has received the TXID, it saves all the settings to flash, and begins scanning the radio channels for a packet.

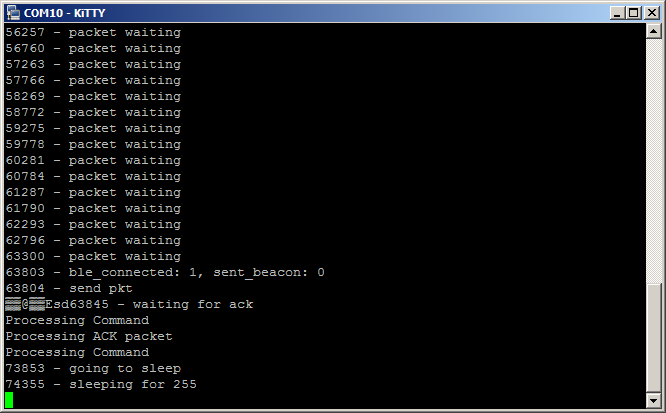
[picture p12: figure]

In this next screenshot, you can see it has got a packet from the Dexcom transmitter. The wixel waits until it has a BLE connection to the phone, then it sends a beacon, then the DATA packet, and waits for an ACK packet.

Once it has this, it saves the settings to flash (mo message above) and then goes to sleep.

It is relatively common for the current xDrip/xDrip+ app to take a while to establish a connection. Hence you can see all the “packet waiting” messages here. The wixel will stay awake for two minutes after a packet capture, waiting for a BLE connection. On some occasions, this will not happen, the wixel will once again go to sleep, and this will appear as a missed packet in xDrip/xDrip+.

At any time when the wixel is awake, you can press the “S” key on the keyboard to get a status display. See below.

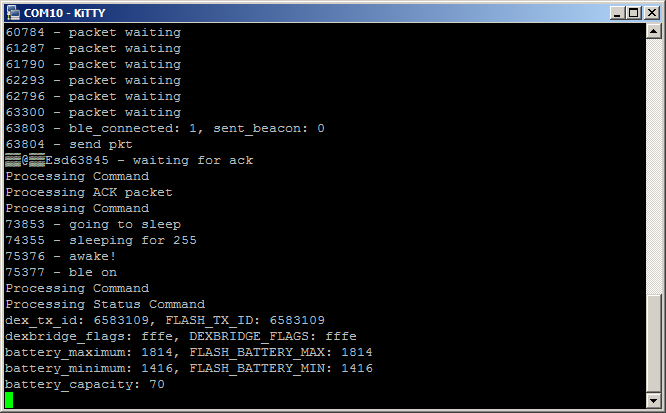
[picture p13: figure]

Here you can see that the wixel has woken up, and turned on the HM-1x (ble on). It has then received a command (me pressing the S key), and is processing it. You can see the battery minimum and maximum are at the default values, and battery capacity has been calculated at 70%.

### Functional Testing

The following tests are carried out on every iteration of the XBridge2 code to ensure it is operating as expected. If you are modifying this code, please perform these tests to ensure you code complies with these minimum functions.

This section on testing assumes you are familiar with Android Studio and the use of the Android Debug logs (ADB).

Testing Pre-requisites
In order to conduct these tests, you will require the following:
- Android Phone with USB debugging enabled.
- Android Studio
- A copy of the XDrip/xDrip+ app repository, that has XBridge support.
- A XBridge unit as per the circuit diagrams in this document.

Test 1 – Broadcast of Beacon Packet and Setting of TXID.
1. Ensure that XDrip/xDrip+ is running and you are viewing the ADB logs.
2. Reload the xBridge2.wxl file onto the wixel module. Note, do NOT just start and stop the wixel program, flash the wixel with the program to clear the Flash storage page used by XBridge2.
3. Observe the ADB log. You should see the following sequence of events;

a. BLE GATT connection series of messages.
b. Messages indicating Receipt of a Beacon Packet.
c. Message saying the Beacon Packet is Wrong.
d. Message “sending message”.
e. Receipt of another Beacon Packet, which is the acknowledgement to the previous one.
4. The wixel will now listen and wait for a Data Packet. There is no ADB log entry showing this listening phase, but there will be log entries when a Data Packet is found.

Test 2 – Reception of Dexcom Data, and initiating sleep.
1. Observe the ADB logs until a message appears showing the reception of a Data Packet. Note, if you are using Android Studio, you can filter on the DexCollectionService to more easily find these.
2. Once this message is received, it will be followed by a “sending message” entry. This is the Data Packet ACK message, and will put the wixel to sleep.
3. A series of messages showing a disconnection of the BLE GATT, and reconnection to the BLE device. This occurs even though the HM-1x module is asleep.

Test 3 – Waking of the wixel and reception of Dexcom Data.
1. Observe the ADB logs until a series of messages appears showing the BLE GATT connection taking place. Note, whilst you would assume this happens at very regular intervals, this is not always the case. It does not mean that the wixel has not woken as expected, nor that it has missed a packet of data. The BLE implementation does not automatically detect when a paired device becomes available again.
2. At some time after the BLE connection is established, the ADB logs will show reception of a Data Packet as per Test 2 above. Depending on timing, it may also show reception of a Beacon Packet, which will only be dealt with if the TXID is NOT what the app is expecting.
3. The wixel will return to sleep as per Test 2 above.

### Usage Notes

There are a few things to keep in mind when using xBridge code, and many of these will apply to using the xDrip-wixel code as well.

1. Charge the bridge when battery capacity falls to 40% or lower. Because we are using a simple battery voltage measure to determine capacity, and LiPo batteries deplete rapidly as they approach minimum voltage lever, it is best to charge it around this point rather than wait. While you may get a few more hours out of the battery at this level, it certainly won’t last a too long.
2. Keep the bridge close to you. While BLE has a bit better range and reliability than the proprietary 2.4GHz protocol used by the Dexcom transmitter, you will still need to keep the bridge within the 20’ / 6m radius of it.
3. Currently the bridge will occasionally miss packets. I am still researching why this is the case. If you use a Qi pad to charge your bridge, this will occur more frequently, likely due to the electro-magnetic field interfering with the Wixel receiver.

4. If you have issues with your phone/Android version and Bluetooth, with the connection and disconnection that xBridge2 uses to save battery, you can try turning BLE sleeping off. Use the “B” command in a serial terminal session to toggle BLE sleeping on or off. Turning BLE sleeping off will cause higher battery drain. However, the connection to the phone will remain stable as long as the bridge does not go out of range of the phone. NOTE: The HM-1x Module will NOT show a Green STATUS LED when the wixel is sleeping. This is an undocumented “feature” of these modules when the serial lines are sent low, which the wixel does when it goes to sleep to save battery.
5. Battery capacity indication in xDrip/xDrip+, as detected and calculated by xBridge2 is NOT accurate. It is an indication only. This is because it depends on measuring the battery voltage, rather than the current into and out of the battery.
Things to note are:
a. When the capacity indication is 100%, the battery may NOT be fully charged. Always charge until your charger board indicates full charge with the green LED.
b. When you stop charging, the capacity will rapidly drop. This is because the voltage used to charge the battery is far higher than the battery’s operating voltage. How far it drops will depend on how charged the battery is. Fully charged, the capacity will drop to around 90% in a few hours, depending on the capacity rating (mAh) of your battery.
c. Once the battery capacity indication reaches 30%, the battery will deplete rapidly. Charge it as soon as possible when this value is reached.

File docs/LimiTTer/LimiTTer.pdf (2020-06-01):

DISCLAIMER: LimiTTer is an experimental DIY project. By building your own transmitter, you are responsible yourself for what you have done. The authors and maintainers of this project cannot be made responsible for any damage or actions.
Don't make any medical decisions based on the data of your sampled device.

Please Note: LimiTTer is not maintained by Abbott. It's only an experimental DIY guide.

Let's get started.
You will need the following things:
- Libre Reader or LibreLink app (for starting a new sensor)
- Smartphone with Android 5.0 at the minimum
- Arduino pro-mini 3V 8Mhz
- USB to TTL Serial Adapter Module
- Solutions Cubed BM019 NFC Module
- HM-11 or HM-17 Bluetooth Module
- Lipo battery 3.7V 100mAh 28x12x5mm
- Lipo charger (Sparkfun Lipo Charger Basic)
- A box 40x40x15mm (big & slim model) or 35x35x15mm (tiny model) (Hammond Manufacturing)
- AWG 30 silicone-cable
- Soldering iron
- Helping Hand
- 2K epoxy glue (Syringe)
- Dremel like multitool with grinding wheel and some cutters

You see that pin 7 + 8 are bridged. This is to give the BM019 enough stable power. If you have problems after a certain time, add pin 4 to that bridge, too.

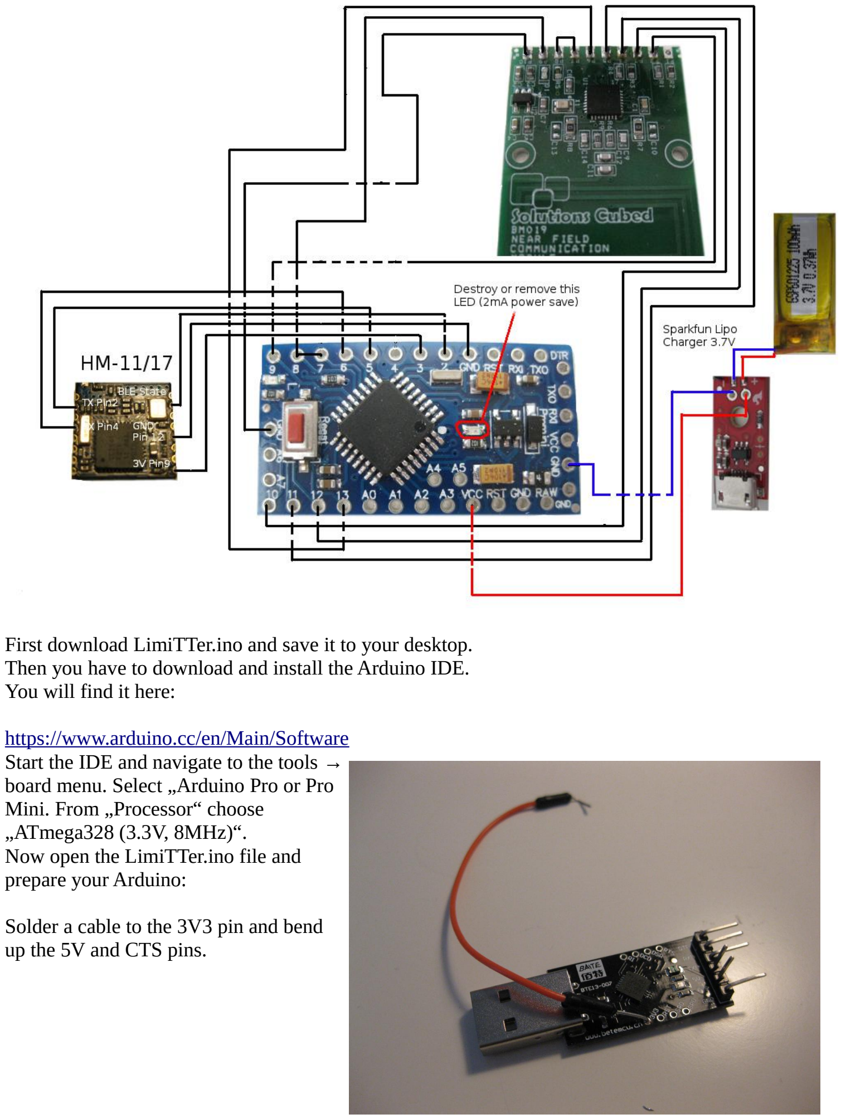
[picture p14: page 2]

First download LimiTTer.ino and save it to your desktop. Then you have to download and install the Arduino IDE. You will find it here:

https://www.arduino.cc/en/Main/Software
Start the IDE and navigate to the tools →
board menu. Select „Arduino Pro or Pro Mini. From „Processor“ choose „ATmega328 (3.3V, 8MHz)“.
Now open the LimiTTer.ino file and prepare your Arduino:

Solder a cable to the 3V3 pin and bend up the 5V and CTS pins.

Plug the adapter into the Arduino and connect it with the USB jack
to your computer. Now you are ready for program the board. Click on the Upload button and hold the 3V wire on a VCC pin of the Arduino. Yes, it's a bit tricky. Of course you can temporarily solder it on that pin ;) When there is no error message and you see „Done uploading“ you can pull it out of the computer.

Now the hardware ...
I will show you 3 models to build:
1. The big one 40x40x15mm
2. The slim one 40x40x10mm
3. The tiny one 35x35x10

For all 3 models i have used cases made by Hammond Manufacturing.

First the big one with a 220mAh lipo (Android 4.3 + 4.4 – BLE always ON)

Solder the 9 wires (40mm long) into the

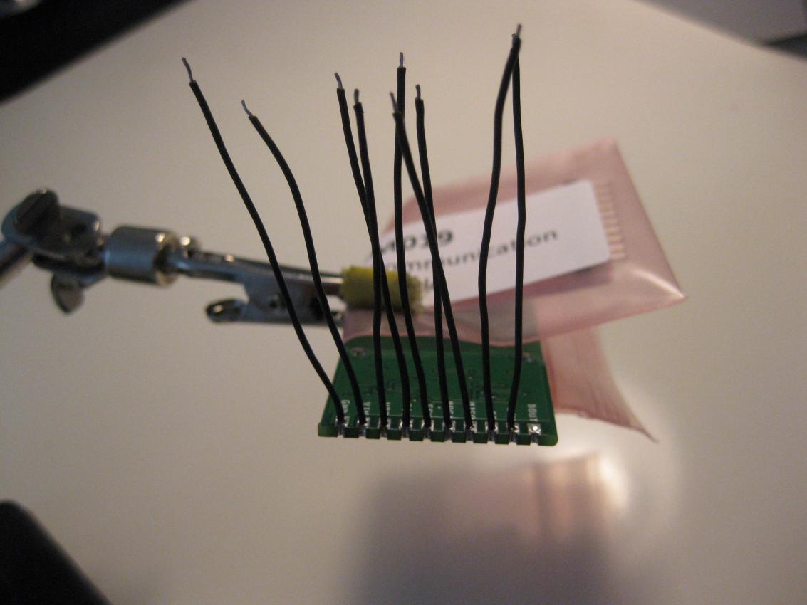
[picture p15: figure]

BM019 contact holes. Connect P7 with P8.

Solder 5 wires on the HM11 module. This is bit tricky, because the contacts are really tiny. I recommend that you first fill the four half holes with blank solder and

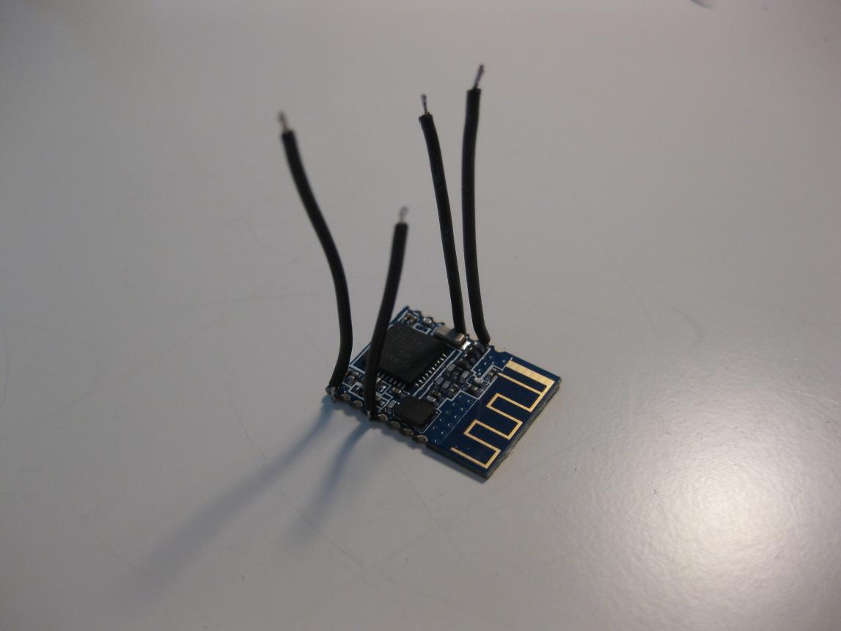
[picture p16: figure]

then hold the wires end on that and heat it. The cables you see on the pic are a bit short. Longer is better. In this pic you only see 4 wires – but you need to solder and connect a fifth one on pin 15 of HM11 to improve battery lifetime. Take a look at the wiring pic above.

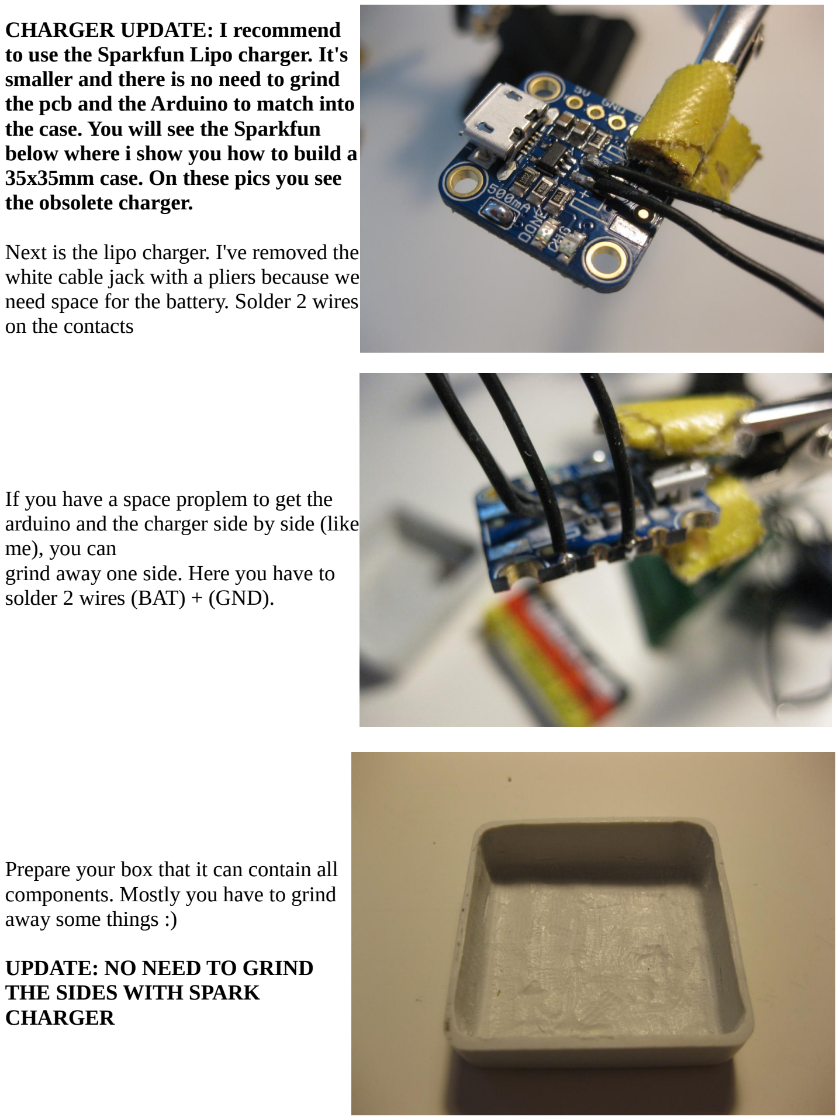
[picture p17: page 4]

CHARGER UPDATE: I recommend to use the Sparkfun Lipo charger. It's smaller and there is no need to grind the pcb and the Arduino to match into the case. You will see the Sparkfun below where i show you how to build a 35x35mm case. On these pics you see the obsolete charger.

Next is the lipo charger. I've removed the white cable jack with a pliers because we need space for the battery. Solder 2 wires on the contacts

If you have a space proplem to get the arduino and the charger side by side (like me), you can
grind away one side. Here you have to solder 2 wires (BAT) + (GND).

Prepare your box that it can contain all components. Mostly you have to grind away some things :)

UPDATE: NO NEED TO GRIND
THE SIDES WITH SPARK
CHARGER

Fits perfect … now! ;)
Now you know the exact position of the loading jack. Mark it and take out the components to grind
a small hole into the box.

Mix a small blob of the epoxy glue and put it on 4 points in the box to fix the charger and put a small blob under the power switch. The glue begins to harden after aprox. 5 minutes. Then make a last fixation and wait for 30 minutes.

Now it's time to bring it all together. I suggest to fill all needed holes on the arduino with solder. Then begin with the HM-11. Desolder or destroy the power

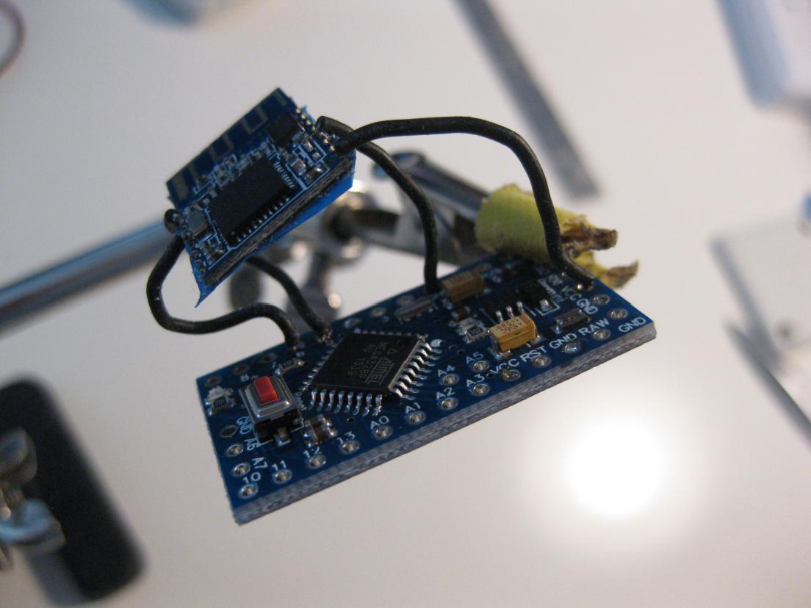
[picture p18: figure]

led of the arduino as you see in the wiring pic. We don't need this and this saves 2mA of power.

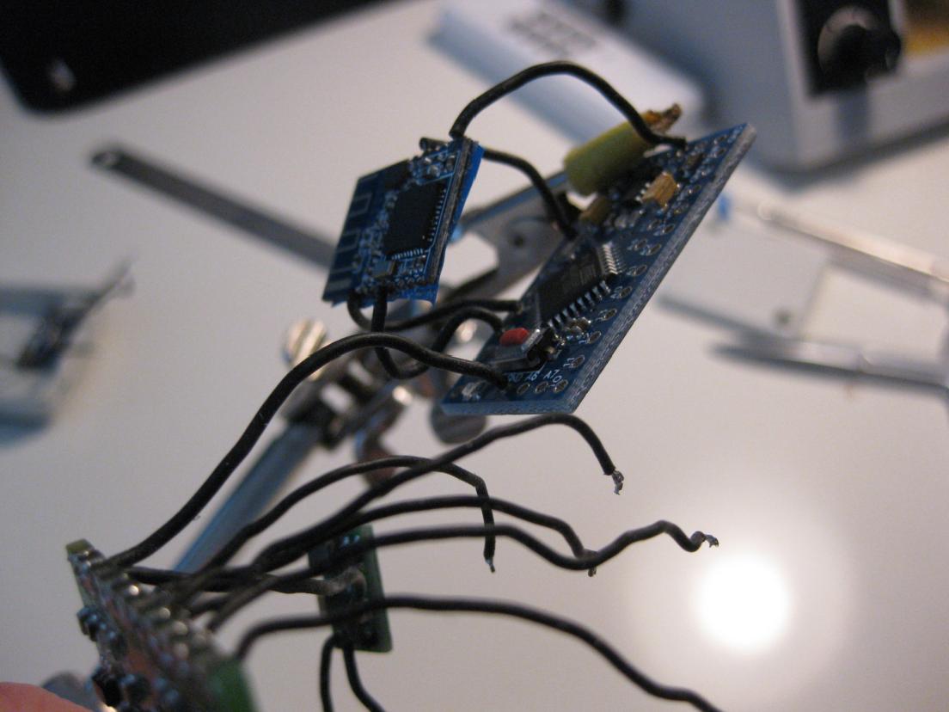
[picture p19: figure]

Then go on with the NFC module.

And now the lipo charger …
You can grind the sides of the Arduino, if you have a space problem (like me).

UPDATE:NO NEED TO GRIND WITH SPARK CHARGER

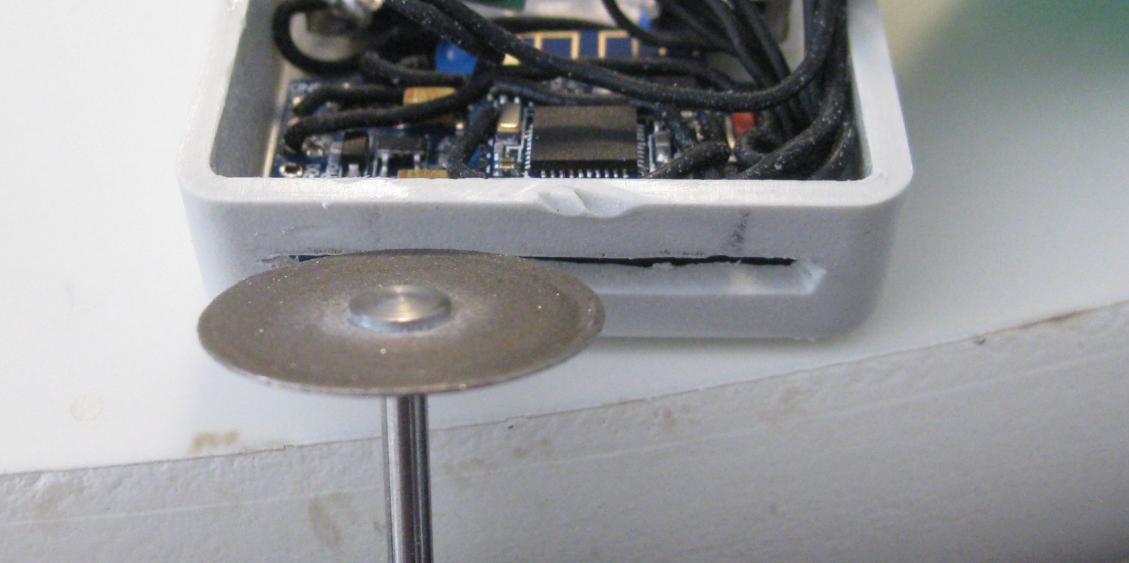
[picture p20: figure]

All 4 PCB's are now wired together. It's time for the recess.

Place the HM-11 / 17 on the Arduino …

...and push the BM019 through the recess …

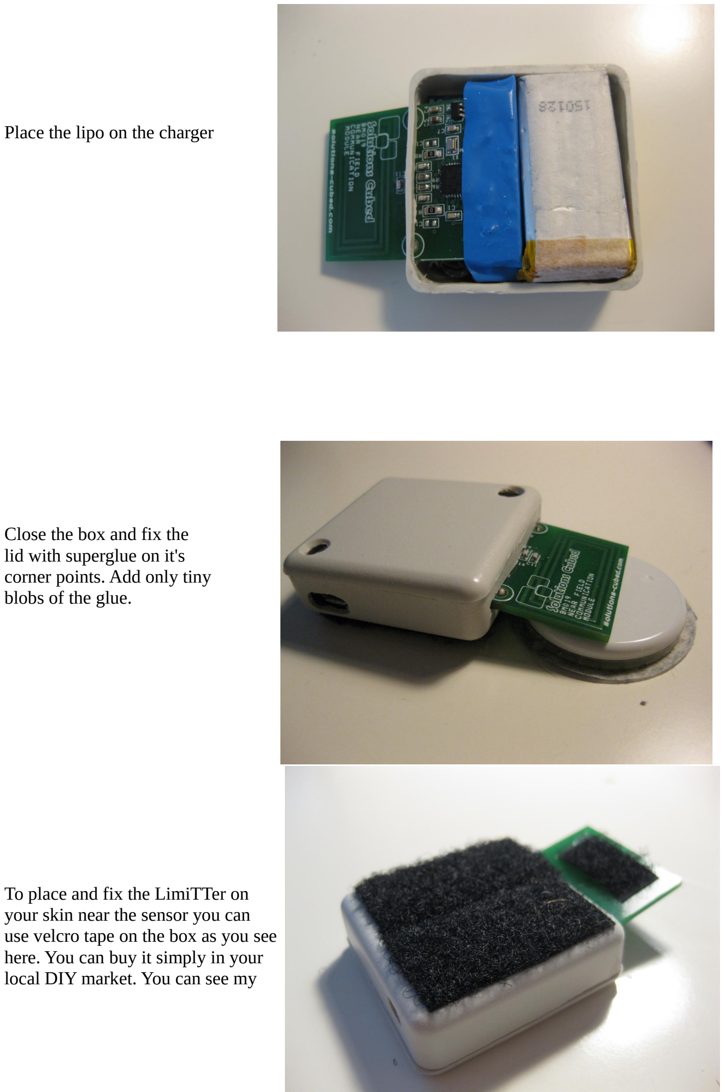
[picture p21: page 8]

Place the lipo on the charger

Close the box and fix the
lid with superglue on it's corner points. Add only tiny blobs of the glue.

To place and fix the LimiTTer on your skin near the sensor you can use velcro tape on the box as you see here. You can buy it simply in your local DIY market. You can see my

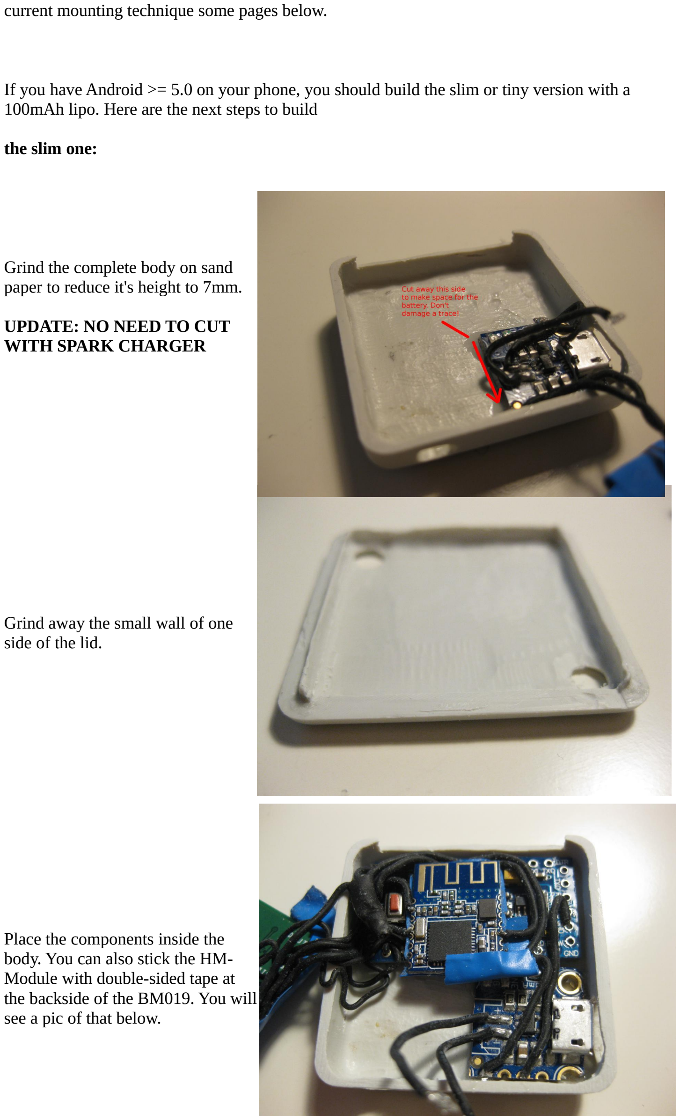
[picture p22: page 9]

current mounting technique some pages below.

If you have Android >= 5.0 on your phone, you should build the slim or tiny version with a 100mAh lipo. Here are the next steps to build

the slim one:

Grind the complete body on sand paper to reduce it's height to 7mm.

UPDATE: NO NEED TO CUT
WITH SPARK CHARGER

Grind away the small wall of one side of the lid.

Place the components inside the body. You can also stick the HM-Module with double-sided tape at the backside of the BM019. You will see a pic of that below.

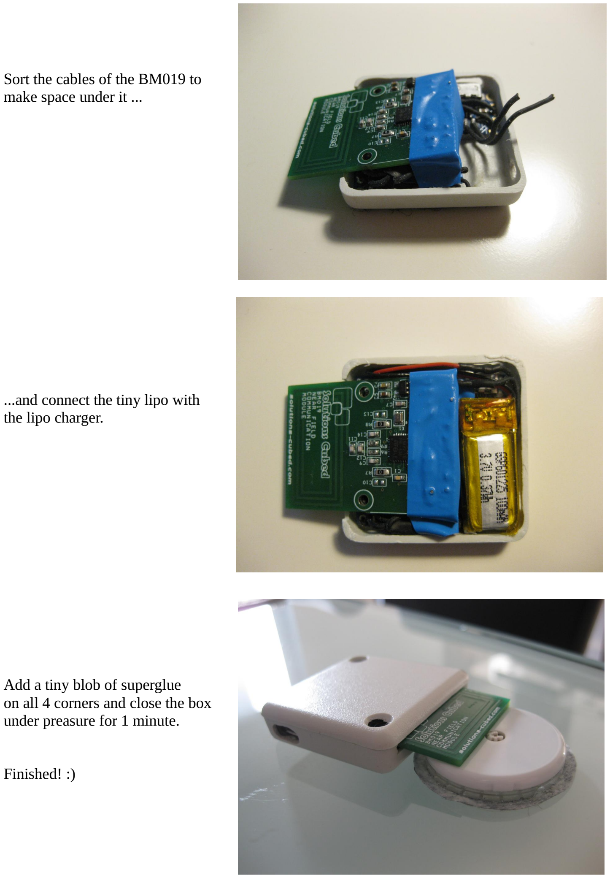
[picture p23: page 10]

Sort the cables of the BM019 to make space under it ...

...and connect the tiny lipo with the lipo charger.

Add a tiny blob of superglue
on all 4 corners and close the box under preasure for 1 minute.

Finished! :)

Mounting methods

Method 1 (Velcro):

Preparing the leg for a
mounting point (velcro tape on Fixomull Stretch) ...

… and stick it.

Method 2 (Magnets):

You need:

- Tegaderm Roll
- Fixomull stretch
- Double sided tape
- 10x Neodym magnet plates (D10x1mm) (eBay search: neodym d10x1)
- Superglue
- Epoxy 2K glue (optional)

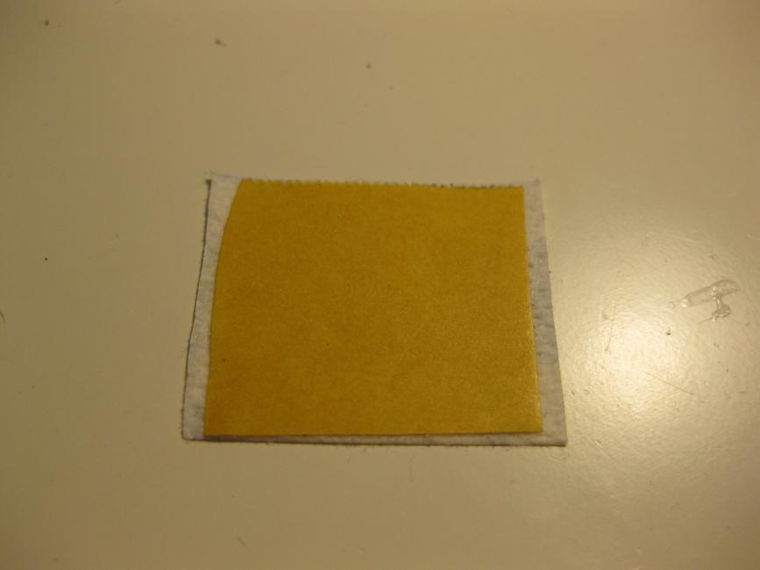
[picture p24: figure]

Cut a piece of Fixomull as the ground plate (about 30x35mm for the tiny LimiTTer).
Cut a little smaller piece of double sided tape and glue it on the Fixomull.

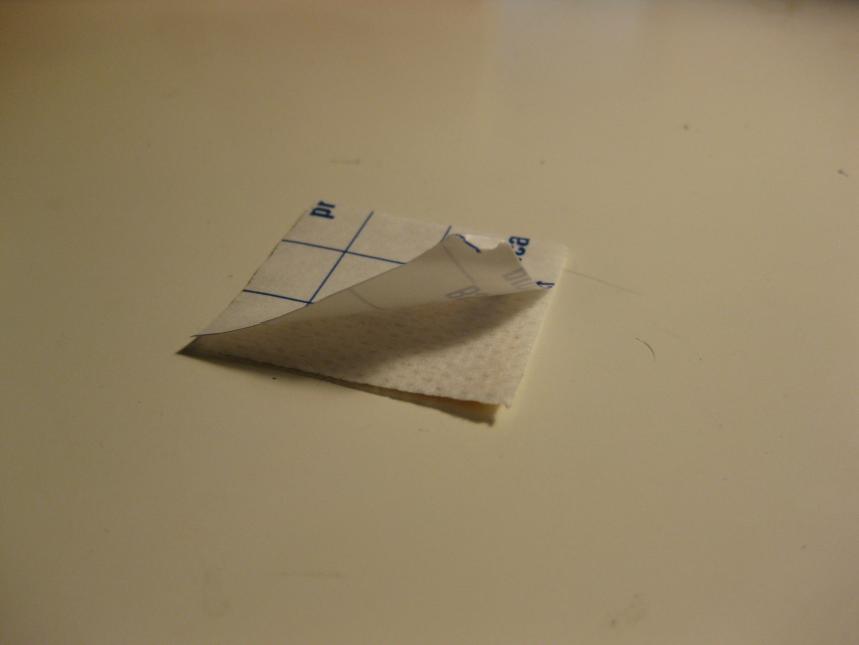
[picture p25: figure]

Remove carefully the back tape of Fixomull.

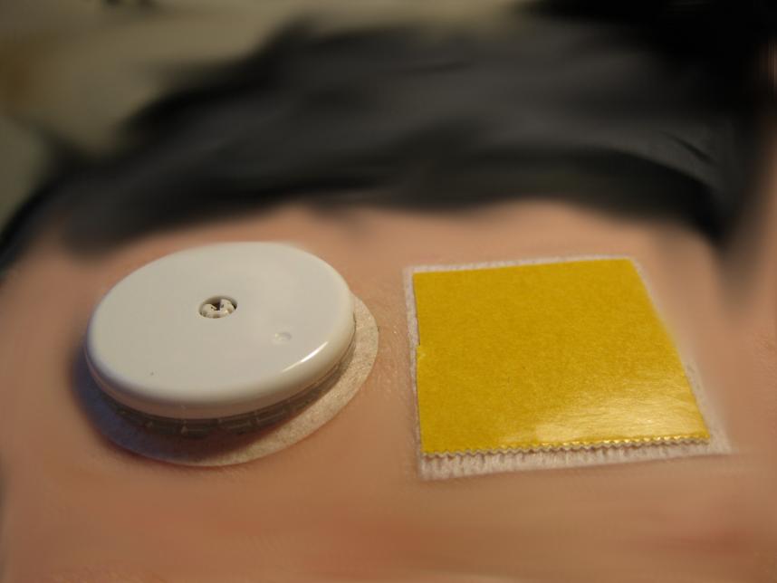
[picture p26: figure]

Place it about 7mm near the sensor.

Remove the upper tape and stick 4 magnets
at the corners. It is necessary that all magnets have the same pole direction, because the 4 magnets on the LimiTTer will be the counterpart.


Cut a piece of Tegaderm roll and glue it on your ground plate. It should overlap it about 7-10mm. Remove it‘s upper tape and push the Tegaderm several times to make sure it fits great.


Take a scissors or another spiky tool and scratch the sensors front area. (Size of about one magnet plate)

Place a blob of superglue in the middle of the


scratched area and push the magnet under preasure on it for some seconds. It‘s best to hold the sensor with the other hand sidely.

Glue the other 5 magnets onto your LimiTTer. Take care of the pole direction. It is the counter part to your ground plate. I would recommend to glue them one by one cause they are acting very strong! I have used epoxy glue for the bottom side and superglue for the one on the BM019.


And voila … sticks perfect and strong …
but easily to take off. You can mount and unmount it blindly. It will find itself the correct position.


Click! … :)
The Tegaderm tape will last the full 14 days.

Now the tiny one:

Cut away the jack of the Spark charger with a pliers.

This is a new black case 35x35x15mm made by Hammond. I have white-painted it later. It is available grey-coloured, too from the manufactor.

Let's grind away the inlay stuff.

...and grind below to make space. There is no need for a huge wall thickness. I have filled the 2 holes with epoxy and grinded the top area on sandpaper after hardened.

Take a pencil and draw a marking
line around the case. 7mm measured from the ground. Grind around above the line with a grinding wheel.

Trim the case by rubbing on sandpaper. Take care not to grind below the marking line.


Put in the charger and mark its position of the jack. Take out the charger and grind a hole at that position.

Grind a recess of 2mm into the front wall.

Glue the charger with 2k-epoxy
into the case. You see, that the ground has been grinded, too. This is necessary but very tricky. The ground plate and the lid plate must be thin to establish space for pcb's and cables.

Here you can see that the Arduino board doesn't match into the case. You have to shorten it and grind the inside of the case.

Grinding both walls to establish space for your Arduino.


Should be enough space. You have to grind the edges of the hardened epoxy glue, too.

Grind both short sides of the Arduino and it's corners.
Do this slowly and frequently check out, if it matches with the case


Now it matches into the box. Solder the VCC and GND wire of the Arduino to the charger. Solder both wires from the lipo battery, too

Place the battery onto the charger.

Stick the HM Module on the back side of the BM019 with double-sided tape.


Place the BM019 in the case on the cables. Take care that it doesn't press the reset button of the Arduino under pressure.

You have to grind away the front plank completely to the ground.

Put some blobs of superglue on the lower portion and stick the lid under pressure.

Charge your LimiTTer.

10-15minutes = 24hrs

Finished. Put on the velcro tape as shown before.

Finally download and install xDrip. You will find a link on the main page (xDrip.md).
Maybe you have to enable the option to install apps from a unknown source.

Then activate bluetooth on your smartphone and start xDrip. Click on the xDrip menu (left upper corner) and select Scan for BT.
Click on scan and every 5 minutes you should see LimiTTer. If you don't see it, there is something wrong with your wiring. Check it out and tap on scan several times. The first time you should see a HMSoft device.
Don't connect to it. When it awakes the second time you should see LimiTTer. If not, hit the reset button of the Arduino and wait 5 minutes again.

Tap on LimiTTer and it will connect to it. After this you have to tap on Start Sensor. Select a few hours or 1 day in


the past to avoid the 120minutes waiting. We don't need this. Now xDrip waits for 2 readings (10 minutes). When they are received you will see Enter 2 Calibrations. Tap on the menu and then on Add double Calibration. Enter the current value from your LibreReader and tap on Done. Now xDrip should show you every 5 minutes a value.
The app will notify you after 1 hour to enter a new calibration. You can ignore this and you should disable calibration notifications in xDrip settings. It's only necessary if the reading is way off or if you want to enter a reading from your bg meter to compensate this to the value of the LibreReader. Read below for more informations.

Acquaint yourself with xDrip. It's a great and matured app with many features. Have a look at the Settings Menu.

Here you see the calibration graph. The only interesting value for the Libre is the intercept. This is the offset with


the raw incoming value from the LimiTTer. Here you see an offset of +0.35 points. You can modify the intercept by making a calibration. As an example:

If your bg meter shows you 135mg/dl and the Libre 105mg/dl, you can make a calibration and enter 135. Then the intercept will change to ~30,0 and xDrip will show you ~135mg/dl, too. Every incoming value will be offset with that intercept and then be displayed on the graph in the main screen.

The LimiTTers power consumption is 0.16mA @ sleep. With a 100mAh lipo it should last ~48hrs but charging it every 24hrs is recommended. Charging time: 25min.

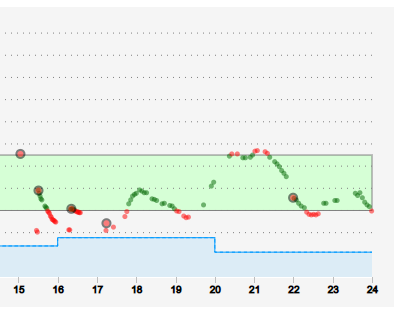
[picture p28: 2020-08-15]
SCANLESS/img/Report.png

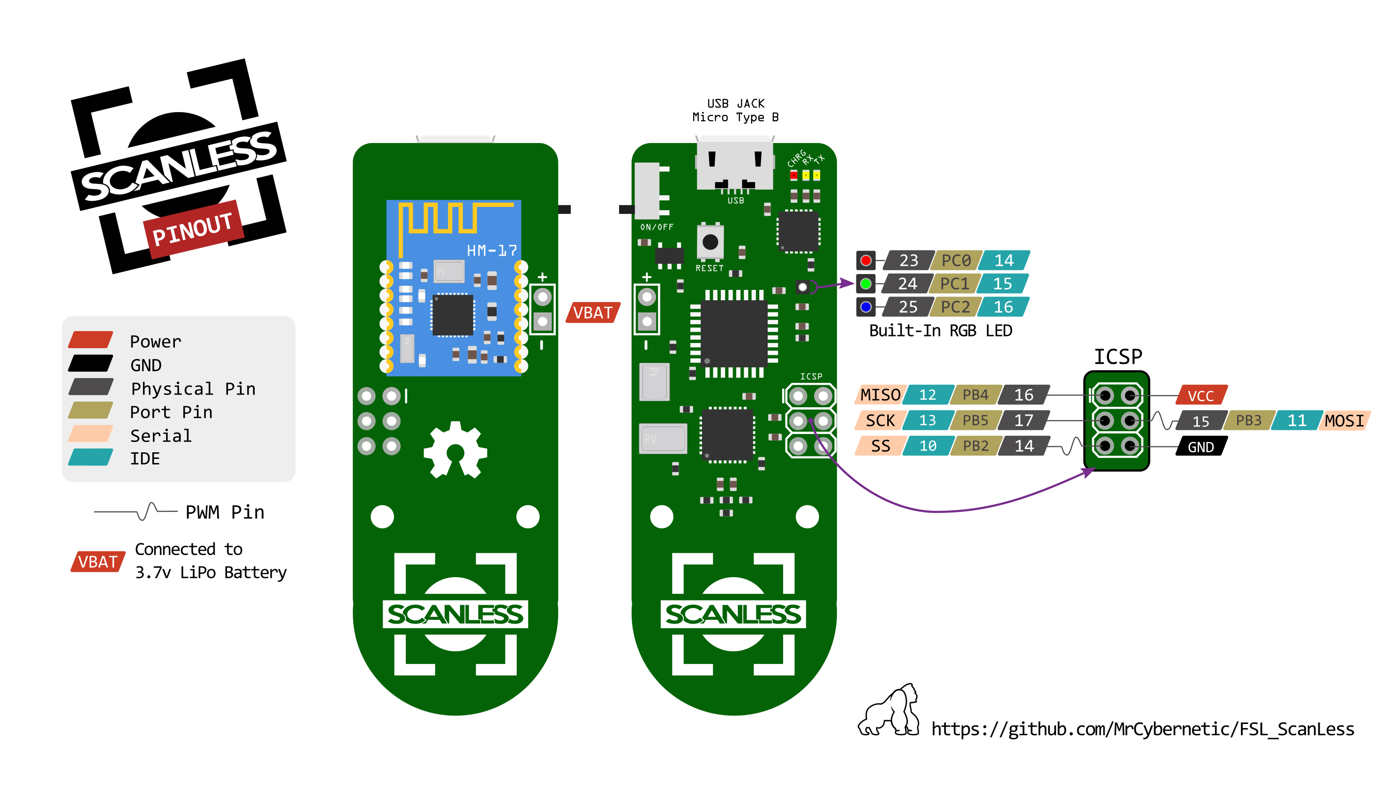
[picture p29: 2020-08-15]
SCANLESS/schematics/ScanLess_Pinout.png

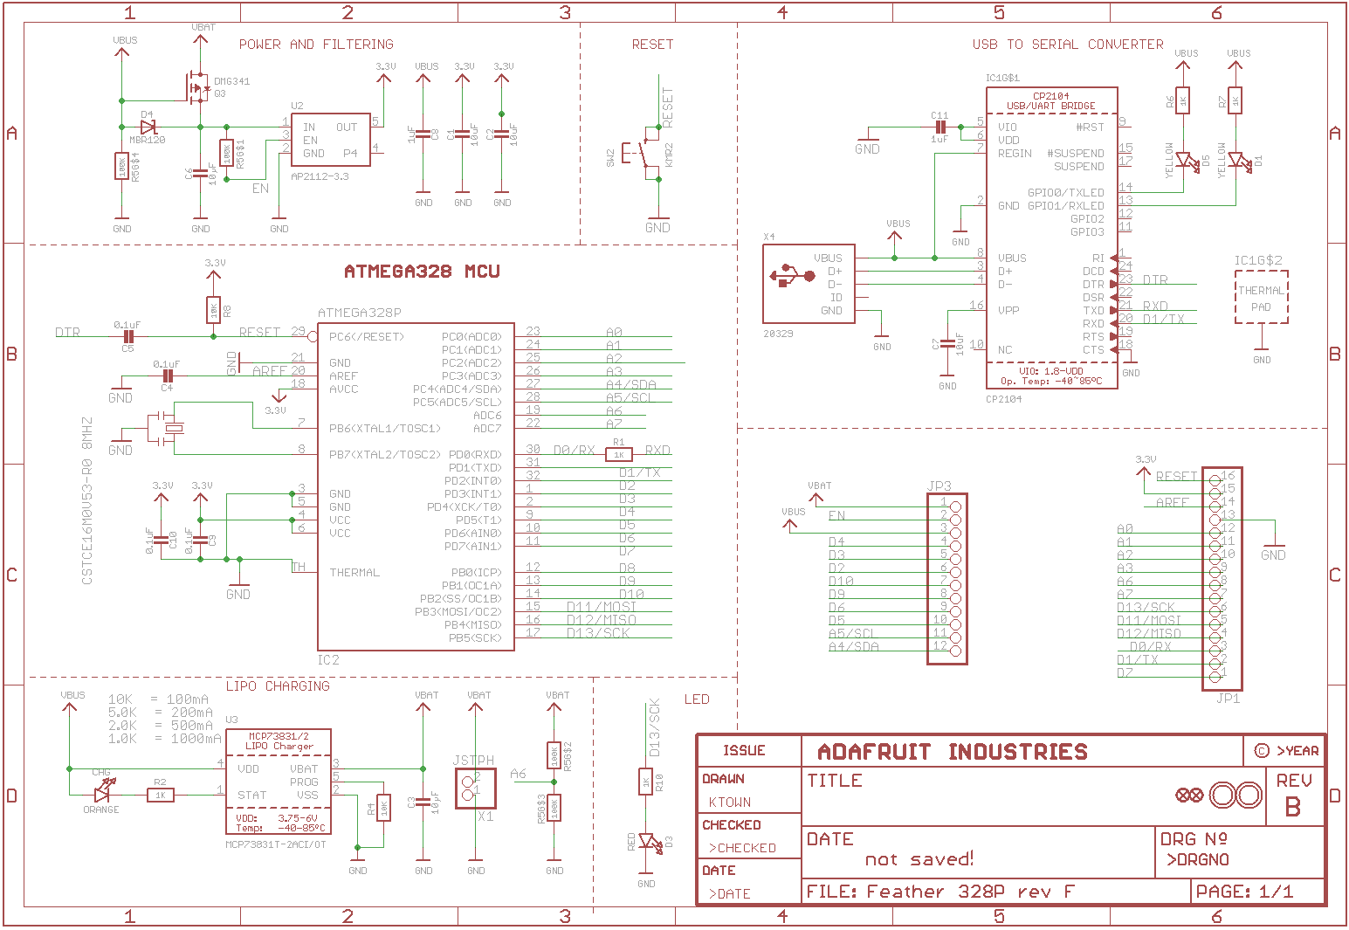
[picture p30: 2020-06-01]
docs/inspiration/arduino_compatibles_schem.png

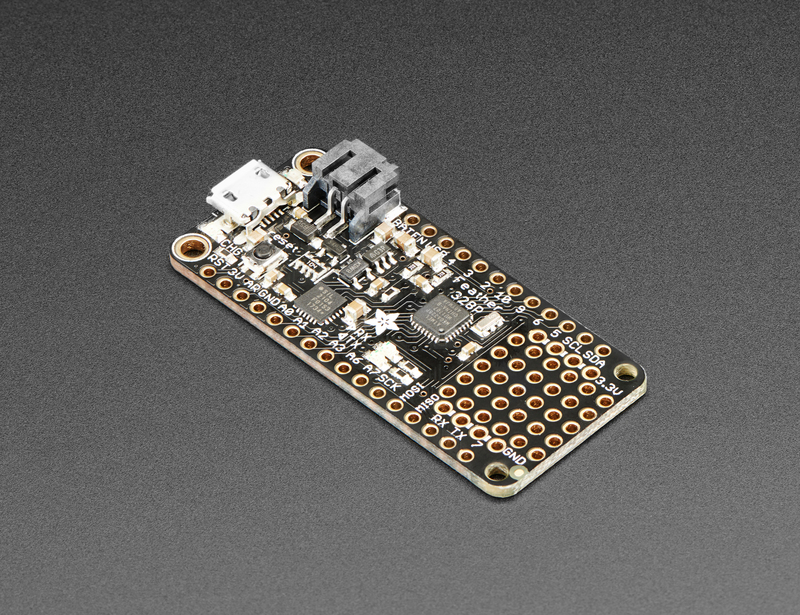
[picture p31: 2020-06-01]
docs/inspiration/Adafruit_Feather_ATmega328P.jpg

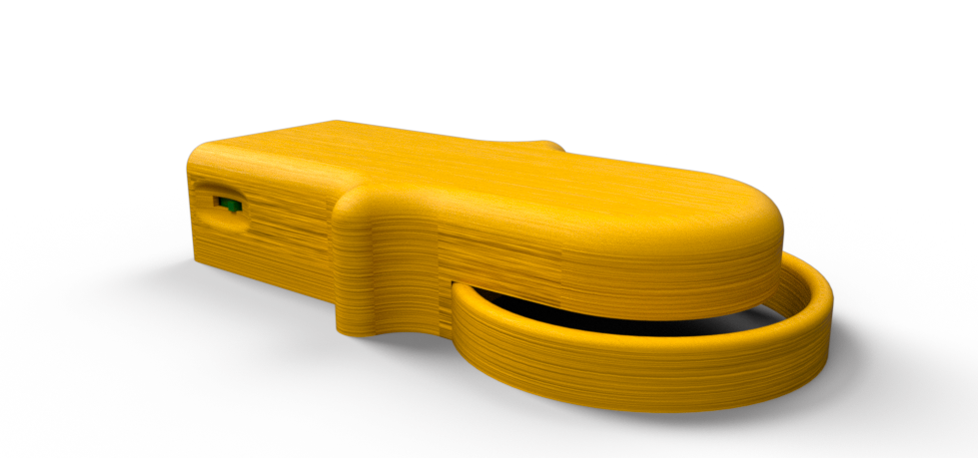
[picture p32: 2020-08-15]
SCANLESS/img/Enclosure1.png

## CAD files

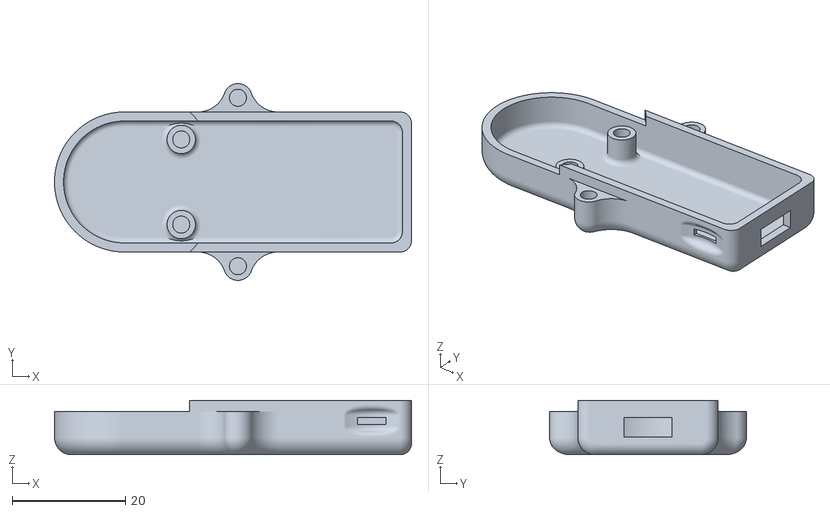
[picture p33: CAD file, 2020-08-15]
SCANLESS/3D_Enclosure/Enclosure - Part 1.stl
63.0 x 34.7 x 9.60

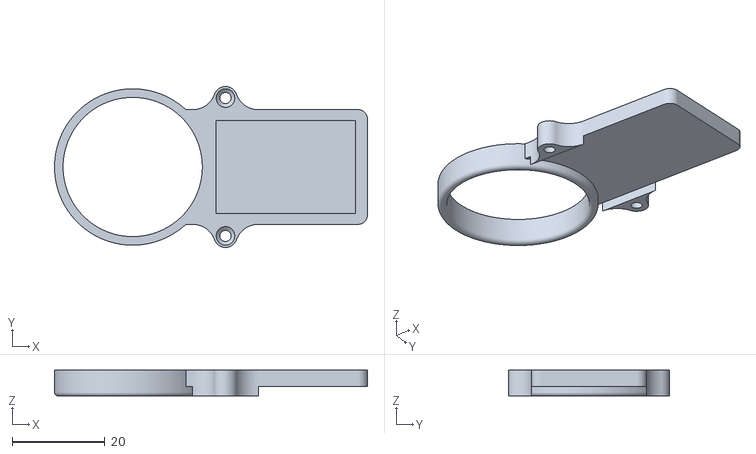
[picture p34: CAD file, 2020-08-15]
SCANLESS/3D_Enclosure/Enclosure - Part 2.stl
67.5 x 34.7 x 5.60

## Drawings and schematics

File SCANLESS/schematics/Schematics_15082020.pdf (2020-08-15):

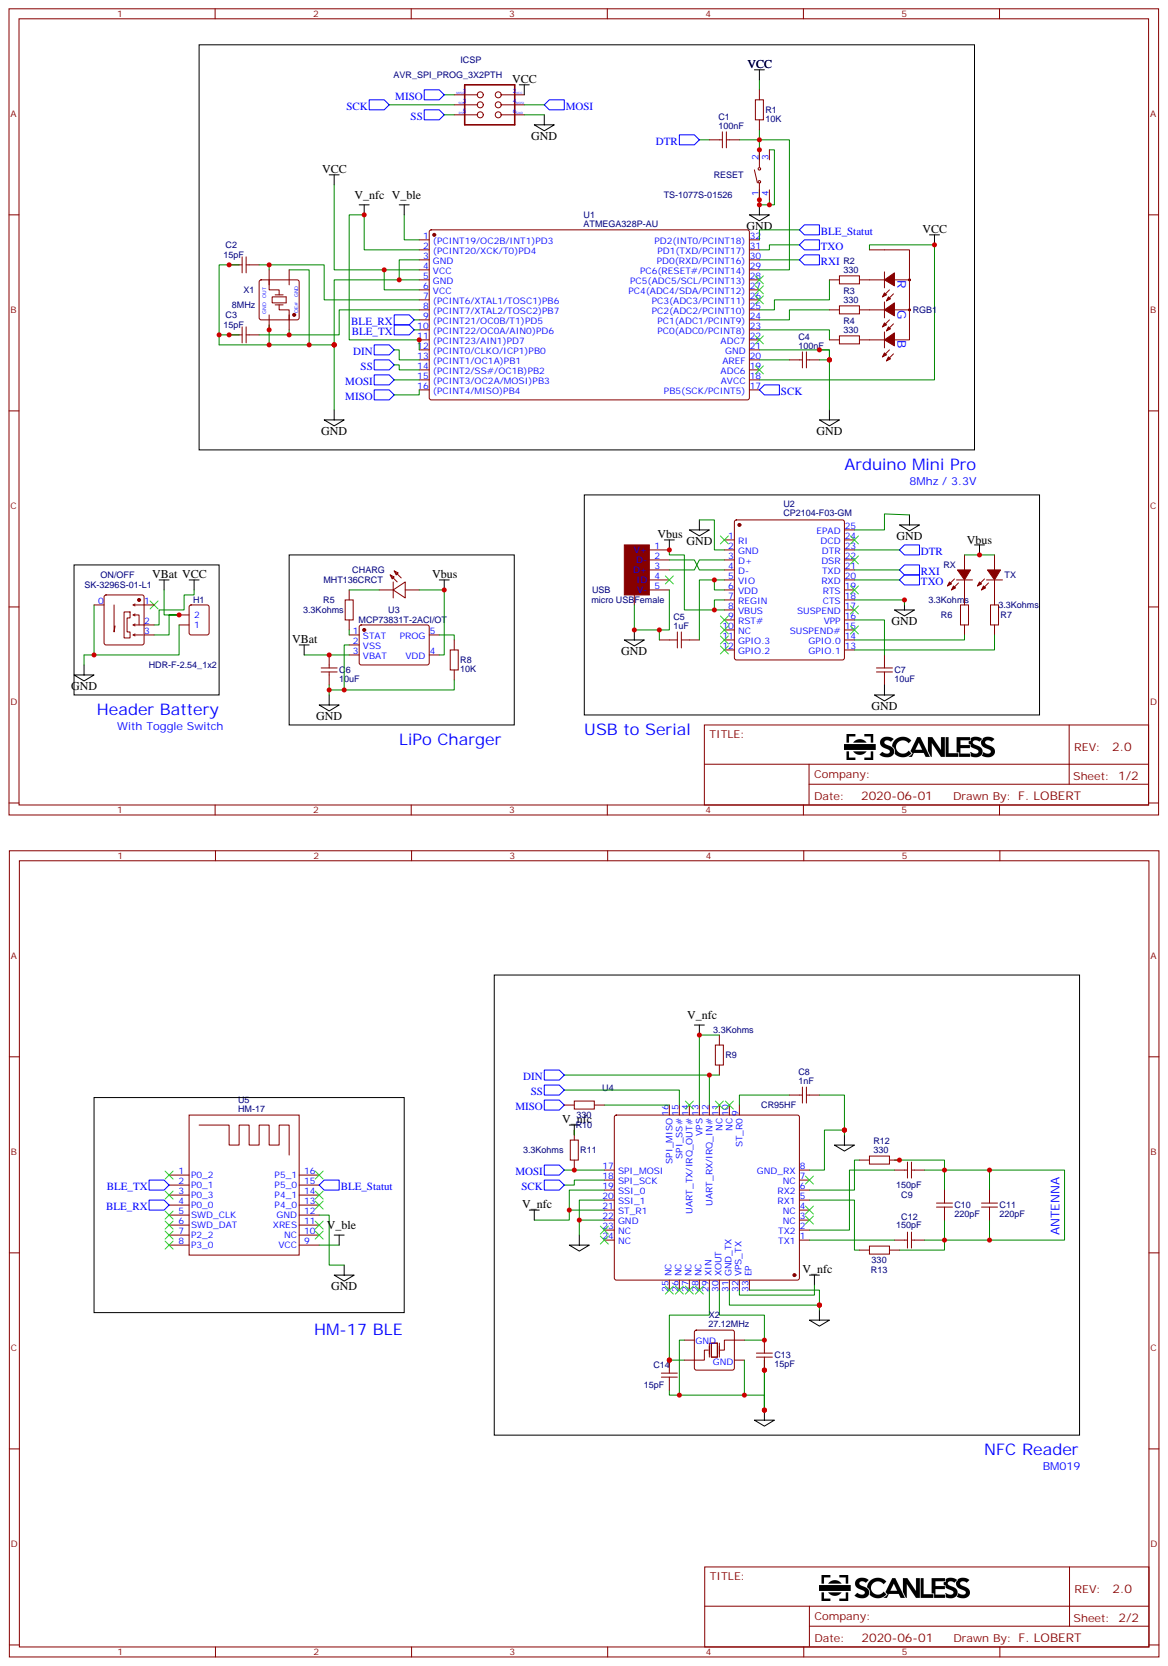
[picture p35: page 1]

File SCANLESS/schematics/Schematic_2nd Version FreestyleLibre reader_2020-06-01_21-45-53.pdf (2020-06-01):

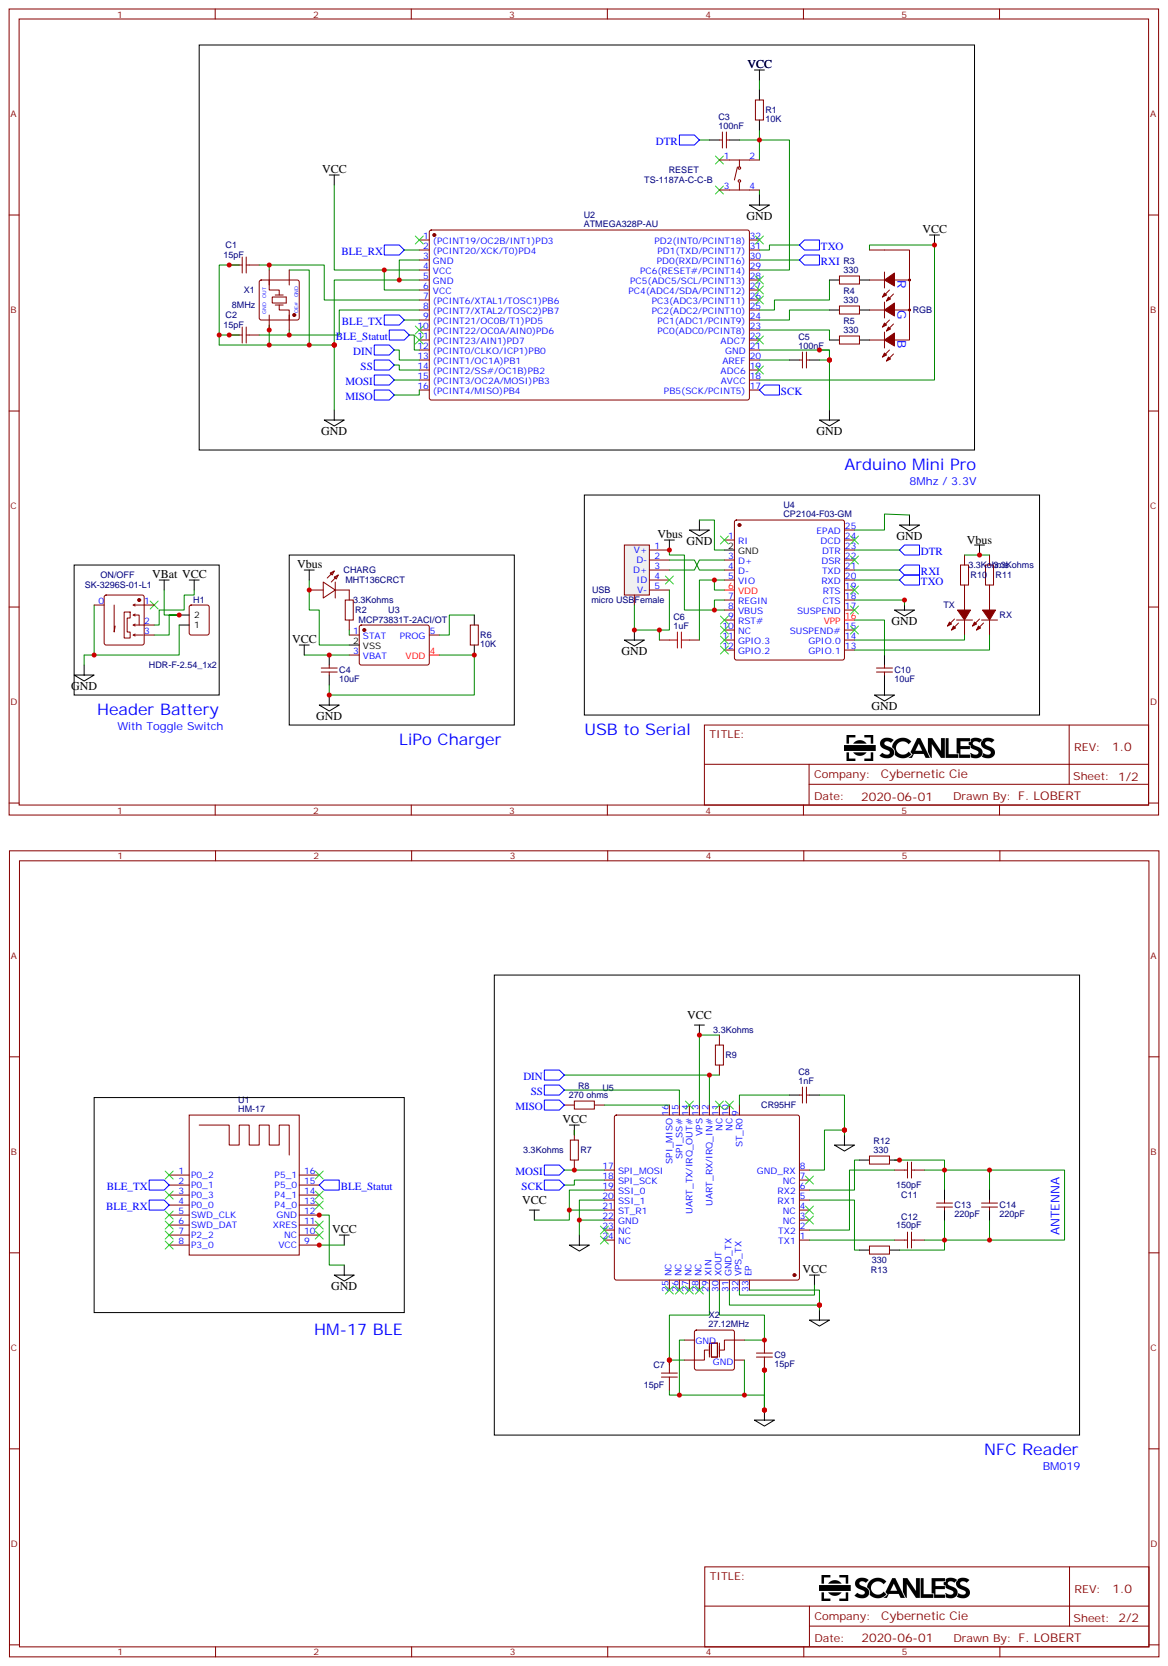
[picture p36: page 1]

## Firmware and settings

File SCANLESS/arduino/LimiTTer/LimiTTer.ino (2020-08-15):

/*Corrected to work with ScanLess and use xBridge2 Protocol*/

/* LimiTTer sketch for the Arduino UNO/Pro-Mini.
 It scans the Freestyle Libre Sensor every 5 minutes
 and sends the data to the xDrip Android app. You can
 see the data in the serial monitor of Arduino IDE, too.
 If you want another scan interval, simply change the
 SLEEP_TIME value. 
 
 This sketch is based on a sample sketch for the BM019 module
 from Solutions Cubed.
 
 Wiring for UNO / Pro-Mini:
 
 Arduino          BM019           BLE-HM11
 IRQ: Pin 9       DIN: pin 2
 SS: pin 10       SS: pin 3
 MOSI: pin 11     MOSI: pin 5 
 MISO: pin 12     MISO: pin4
 SCK: pin 13      SCK: pin 6
 I/O: pin 2                   BLE_CHK: pin 15 
 I/O: pin 3                       VCC: pin 9 
 I/O: pin 5                        TX: pin 2
 I/O: pin 6                        RX: pin 4
 */

#include <SPI.h>
#include <SoftwareSerial.h>
#include <avr/sleep.h> 
#include <avr/power.h>
#include <avr/wdt.h>

#define MIN_V 3000 // battery empty level
#define MAX_V 5000 // battery full level
#define MAX_BLE_WAIT 80 // Maximum bluetooth re-connect time in seconds 
#define SLEEP_TIME 25 // SleepTime (7 points are about 1 minute)
#define MAX_NFC_READTRIES 12 // Amount of tries for every nfc block-scan

const int SSPin = 10;  // Slave Select pin
const int IRQPin = 9;  // Sends wake-up pulse for BM019
const int NFCPin1 = 7; // Power pin BM019
const int NFCPin2 = 8; // Power pin BM019
const int NFCPin3 = 4; // Power pin BM019
const int BLEPin = 3; // BLE power pin.
const int BLEState = 2; // BLE connection state pin
const int MOSIPin = 11;
const int SCKPin = 13;
byte RXBuffer[24];
byte NFCReady = 0;  // used to track NFC state
byte FirstRun = 1;
byte batteryLow;
int batteryPcnt;
long batteryMv;
int noDiffCount = 0;
int sensorMinutesElapse;
float lastGlucose;
float trend[16];
bool bdebug = false;

typedef struct _nRawRecord {                // structure of a Dexcom raw record we will send.
  unsigned char size; //size of the packet.
  unsigned char cmd_code; // code for this data packet.  Always 00 for a Dexcom data packet.
  unsigned long raw;  //"raw" BGL value. ??? use unfiltered NFC readings here?
  unsigned long filtered; //"filtered" BGL value
  unsigned char dex_battery;  //battery value
  unsigned char my_battery; //xBridge battery value
  unsigned long dex_src_id;   //raw TXID of the Dexcom Transmitter
  unsigned long delay;
  unsigned char function; // Byte representing the xBridge code funcitonality.  01 = this level.
} 
nRawRecord;



SoftwareSerial ble_Serial(6, 5); // RX | TX

void setup() {
  pinMode(IRQPin, OUTPUT);
  digitalWrite(IRQPin, HIGH); 
  pinMode(SSPin, OUTPUT);
  digitalWrite(SSPin, HIGH);
  pinMode(NFCPin1, OUTPUT);
  digitalWrite(NFCPin1, HIGH);
  pinMode(NFCPin2, OUTPUT);
  digitalWrite(NFCPin2, HIGH);
  pinMode(NFCPin3, OUTPUT);
  digitalWrite(NFCPin3, HIGH);
  pinMode(BLEPin, OUTPUT);
  digitalWrite(BLEPin, HIGH);
  pinMode(BLEState, INPUT);
  pinMode(MOSIPin, OUTPUT);
  pinMode(SCKPin, OUTPUT);

  if (bdebug) Serial.begin(9600);

  long bleBaudrate[8] = {
    1200,2400,4800,9600,19200,38400,57600,115200  };
  for (int i=0; i<8; i++)
  {
    ble_Serial.begin(bleBaudrate[i]);
    ble_Serial.write("AT");
    delay(500);
    char c = ble_Serial.read();
    char d = ble_Serial.read();
    if (c == 'O' && d == 'K')
      break;
  }
  delay(100);
  ble_Serial.write("AT+NAMELimiTTerScan");
  delay(500);
  ble_Serial.write("AT+RESET");
  delay(500);

  SPI.begin();
  SPI.setDataMode(SPI_MODE0);
  SPI.setBitOrder(MSBFIRST);
  SPI.setClockDivider(SPI_CLOCK_DIV32);

  delay(10);                      // send a wake up
  digitalWrite(IRQPin, LOW);      // pulse to put the 
  delayMicroseconds(100);         // BM019 into SPI
  digitalWrite(IRQPin, HIGH);     // mode 
  delay(10);
  digitalWrite(IRQPin, LOW);
}

void restartBLE() {
  digitalWrite(BLEPin, HIGH);
  digitalWrite(5, HIGH);
  digitalWrite(6, HIGH);
  delay(500);
  ble_Serial.write("AT+RESET");
  delay(500);
}

void SetProtocol_Command() {

  digitalWrite(SSPin, LOW);
  SPI.transfer(0x00);  // SPI control byte to send command to CR95HF
  SPI.transfer(0x02);  // Set protocol command
  SPI.transfer(0x02);  // length of data to follow
  SPI.transfer(0x01);  // code for ISO/IEC 15693
  SPI.transfer(0x0D);  // Wait for SOF, 10% modulation, append CRC
  digitalWrite(SSPin, HIGH);
  delay(1);

  digitalWrite(SSPin, LOW);
  while(RXBuffer[0] != 8)
  {
    RXBuffer[0] = SPI.transfer(0x03);  // Write 3 until
    RXBuffer[0] = RXBuffer[0] & 0x08;  // bit 3 is set
  }
  digitalWrite(SSPin, HIGH);
  delay(1);

  digitalWrite(SSPin, LOW);
  SPI.transfer(0x02);   // SPI control byte for read         
  RXBuffer[0] = SPI.transfer(0);  // response code
  RXBuffer[1] = SPI.transfer(0);  // length of data
  digitalWrite(SSPin, HIGH);

  if ((RXBuffer[0] == 0) & (RXBuffer[1] == 0))  // is response code good?
  {
    if (bdebug) Serial.println("Protocol Set Command OK");
    NFCReady = 1; // NFC is ready
  }
  else
  {
    if (bdebug) Serial.println("Protocol Set Command FAIL");
    NFCReady = 0; // NFC not ready
  }
}

void Inventory_Command() {

  digitalWrite(SSPin, LOW);
  SPI.transfer(0x00);  // SPI control byte to send command to CR95HF
  SPI.transfer(0x04);  // Send Receive CR95HF command
  SPI.transfer(0x03);  // length of data that follows is 0
  SPI.transfer(0x26);  // request Flags byte
  SPI.transfer(0x01);  // Inventory Command for ISO/IEC 15693
  SPI.transfer(0x00);  // mask length for inventory command
  digitalWrite(SSPin, HIGH);
  delay(1);

  digitalWrite(SSPin, LOW);
  while(RXBuffer[0] != 8)
  {
    RXBuffer[0] = SPI.transfer(0x03);  // Write 3 until
    RXBuffer[0] = RXBuffer[0] & 0x08;  // bit 3 is set
  }
  digitalWrite(SSPin, HIGH);
  delay(1);

  digitalWrite(SSPin, LOW);
  SPI.transfer(0x02);   // SPI control byte for read         
  RXBuffer[0] = SPI.transfer(0);  // response code
  RXBuffer[1] = SPI.transfer(0);  // length of data
  for (byte i=0;i<RXBuffer[1];i++)      
    RXBuffer[i+2]=SPI.transfer(0);  // data
  digitalWrite(SSPin, HIGH);
  delay(1);

  if (RXBuffer[0] == 128)  // is response code good?
  {
    if (bdebug) Serial.println("Sensor in range ... OK");
    NFCReady = 2;
  }
  else
  {
    if (bdebug) Serial.println("Sensor out of range");
    NFCReady = 1;
  }
}

float Read_Memory() {

  byte oneBlock[8];
  String hexPointer = "";
  String trendValues = "";
  String hexMinutes = "";
  String elapsedMinutes = "";
  float trendOneGlucose;
  float trendTwoGlucose;
  float currentGlucose;
  float shownGlucose;
  float averageGlucose = 0;
  int glucosePointer;
  int validTrendCounter = 0;
  float validTrend[16];
  byte readError = 0;
  int readTry;

  for ( int b = 3; b < 16; b++) {
    readTry = 0;
    do {
      readError = 0;   
      digitalWrite(SSPin, LOW);
      SPI.transfer(0x00);  // SPI control byte to send command to CR95HF
      SPI.transfer(0x04);  // Send Receive CR95HF command
      SPI.transfer(0x03);  // length of data that follows
      SPI.transfer(0x02);  // request Flags byte
      SPI.transfer(0x20);  // Read Single Block command for ISO/IEC 15693
      SPI.transfer(b);  // memory block address
      digitalWrite(SSPin, HIGH);
      delay(1);

      digitalWrite(SSPin, LOW);
      while(RXBuffer[0] != 8)
      {
        RXBuffer[0] = SPI.transfer(0x03);  // Write 3 until
        RXBuffer[0] = RXBuffer[0] & 0x08;  // bit 3 is set
      }
      digitalWrite(SSPin, HIGH);
      delay(1);

      digitalWrite(SSPin, LOW);
      SPI.transfer(0x02);   // SPI control byte for read         
      RXBuffer[0] = SPI.transfer(0);  // response code
      RXBuffer[1] = SPI.transfer(0);  // length of data
      for (byte i=0;i<RXBuffer[1];i++)
        RXBuffer[i+2]=SPI.transfer(0);  // data
      if (RXBuffer[0] != 128)
        readError = 1;  
      digitalWrite(SSPin, HIGH);
      delay(1);

      for (int i = 0; i < 8; i++)
        oneBlock[i] = RXBuffer[i+3];

      char str[24];
      unsigned char * pin = oneBlock;
      const char * hex = "0123456789ABCDEF";
      char * pout = str;
      for(; pin < oneBlock+8; pout+=2, pin++) {
        pout[0] = hex[(*pin>>4) & 0xF];
        pout[1] = hex[ *pin     & 0xF];
      }
      pout[0] = 0;
      if (!readError)       // is response code good?
      { 
        if (bdebug) Serial.println(str);
        trendValues += str;
      }
      readTry++;
    } 
    while( (readError) && (readTry < MAX_NFC_READTRIES) );

  }
  readTry = 0;
  do {
    readError = 0;  
    digitalWrite(SSPin, LOW);
    SPI.transfer(0x00);  // SPI control byte to send command to CR95HF
    SPI.transfer(0x04);  // Send Receive CR95HF command
    SPI.transfer(0x03);  // length of data that follows
    SPI.transfer(0x02);  // request Flags byte
    SPI.transfer(0x20);  // Read Single Block command for ISO/IEC 15693
    SPI.transfer(39);  // memory block address
    digitalWrite(SSPin, HIGH);
    delay(1);

    digitalWrite(SSPin, LOW);
    while(RXBuffer[0] != 8)
    {
      RXBuffer[0] = SPI.transfer(0x03);  // Write 3 until
      RXBuffer[0] = RXBuffer[0] & 0x08;  // bit 3 is set
    }
    digitalWrite(SSPin, HIGH);
    delay(1);

    digitalWrite(SSPin, LOW);
    SPI.transfer(0x02);   // SPI control byte for read         
    RXBuffer[0] = SPI.transfer(0);  // response code
    RXBuffer[1] = SPI.transfer(0);  // length of data
    for (byte i=0;i<RXBuffer[1];i++)
      RXBuffer[i+2]=SPI.transfer(0);  // data
    if (RXBuffer[0] != 128)
      readError = 1;  
    digitalWrite(SSPin, HIGH);
    delay(1);

    for (int i = 0; i < 8; i++)
      oneBlock[i] = RXBuffer[i+3];

    char str[24];
    unsigned char * pin = oneBlock;
    const char * hex = "0123456789ABCDEF";
    char * pout = str;
    for(; pin < oneBlock+8; pout+=2, pin++) {
      pout[0] = hex[(*pin>>4) & 0xF];
      pout[1] = hex[ *pin     & 0xF];
    }
    pout[0] = 0;
    if (!readError)
      elapsedMinutes += str;
    readTry++;
  } 
  while( (readError) && (readTry < MAX_NFC_READTRIES) );

  if (!readError)
  {
    hexMinutes = elapsedMinutes.substring(10,12) + elapsedMinutes.substring(8,10);
    hexPointer = trendValues.substring(4,6);
    sensorMinutesElapse = strtoul(hexMinutes.c_str(), NULL, 16);
    glucosePointer = strtoul(hexPointer.c_str(), NULL, 16);

    if (bdebug) {
      Serial.println("");
      Serial.print("Glucose pointer: ");
      Serial.print(glucosePointer);
      Serial.println("");
    }

    int ii = 0;
    for (int i=8; i<=200; i+=12) {
      if (glucosePointer == ii)
      {
        if (glucosePointer == 0)
        {
          String trendNow = trendValues.substring(190,192) + trendValues.substring(188,190);
          String trendOne = trendValues.substring(178,180) + trendValues.substring(176,178);
          String trendTwo = trendValues.substring(166,168) + trendValues.substring(164,166);
          currentGlucose = Glucose_Reading(strtoul(trendNow.c_str(), NULL ,16));
          trendOneGlucose = Glucose_Reading(strtoul(trendOne.c_str(), NULL ,16));
          trendTwoGlucose = Glucose_Reading(strtoul(trendTwo.c_str(), NULL ,16));

          if (FirstRun == 1)
            lastGlucose = currentGlucose;

          if (((lastGlucose - currentGlucose) > 50) || ((currentGlucose - lastGlucose) > 50))
          {
            if (((lastGlucose - trendOneGlucose) > 50) || ((trendOneGlucose - lastGlucose) > 50))
              currentGlucose = trendTwoGlucose;
            else
              currentGlucose = trendOneGlucose;
          }
        }
        else if (glucosePointer == 1)
        {
          String trendNow = trendValues.substring(i-10,i-8) + trendValues.substring(i-12,i-10);
          String trendOne = trendValues.substring(190,192) + trendValues.substring(188,190);
          String trendTwo = trendValues.substring(178,180) + trendValues.substring(176,178);
          currentGlucose = Glucose_Reading(strtoul(trendNow.c_str(), NULL ,16));
          trendOneGlucose = Glucose_Reading(strtoul(trendOne.c_str(), NULL ,16));
          trendTwoGlucose = Glucose_Reading(strtoul(trendTwo.c_str(), NULL ,16));

          if (FirstRun == 1)
            lastGlucose = currentGlucose;

          if (((lastGlucose - currentGlucose) > 50) || ((currentGlucose - lastGlucose) > 50))
          {
            if (((lastGlucose - trendOneGlucose) > 50) || ((trendOneGlucose - lastGlucose) > 50))
              currentGlucose = trendTwoGlucose;
            else
              currentGlucose = trendOneGlucose;
          }
        }
        else
        {
          String trendNow = trendValues.substring(i-10,i-8) + trendValues.substring(i-12,i-10);
          String trendOne = trendValues.substring(i-22,i-20) + trendValues.substring(i-24,i-22);
          String trendTwo = trendValues.substring(i-34,i-32) + trendValues.substring(i-36,i-34);
          currentGlucose = Glucose_Reading(strtoul(trendNow.c_str(), NULL ,16));
          trendOneGlucose = Glucose_Reading(strtoul(trendOne.c_str(), NULL ,16));
          trendTwoGlucose = Glucose_Reading(strtoul(trendTwo.c_str(), NULL ,16));


          if (FirstRun == 1)
            lastGlucose = currentGlucose;

          if (((lastGlucose - currentGlucose) > 50) || ((currentGlucose - lastGlucose) > 50))
          {
            if (((lastGlucose - trendOneGlucose) > 50) || ((trendOneGlucose - lastGlucose) > 50))
              currentGlucose = trendTwoGlucose;
            else
              currentGlucose = trendOneGlucose;
          }
        }
      }  

      ii++;
    }

    for (int i=8, j=0; i<200; i+=12,j++) {
      String t = trendValues.substring(i+2,i+4) + trendValues.substring(i,i+2);
      trend[j] = Glucose_Reading(strtoul(t.c_str(), NULL ,16));
    }

    for (int i=0; i<16; i++)
    {
      if (((lastGlucose - trend[i]) > 50) || ((trend[i] - lastGlucose) > 50)) // invalid trend check
        continue;
      else
      {
        validTrend[validTrendCounter] = trend[i];
        validTrendCounter++;
      }
    }

    if (validTrendCounter > 0)
    { 
      for (int i=0; i < validTrendCounter; i++)
        averageGlucose += validTrend[i];

      averageGlucose = averageGlucose / validTrendCounter;

      if (((lastGlucose - currentGlucose) > 50) || ((currentGlucose - lastGlucose) > 50))
        shownGlucose = averageGlucose; // If currentGlucose is still invalid take the average value
      else
        shownGlucose = currentGlucose; // All went well. Take and show the current value
    }
    else
      shownGlucose = currentGlucose; // If all is going wrong, nevertheless take and show a value 

      if ((lastGlucose == currentGlucose) && (sensorMinutesElapse > 21000)) // Expired sensor check
      noDiffCount++;

    if (lastGlucose != currentGlucose) // Reset the counter
      noDiffCount = 0;

    if (currentGlucose != 0)
      lastGlucose = currentGlucose; 


    NFCReady = 2;
    FirstRun = 0;

    if (noDiffCount > 5)
      return 0;
    else  
      return shownGlucose;

  }
  else
  {
    if (bdebug) Serial.print("Read Memory Block Command FAIL");
    NFCReady = 0;
    readError = 0;
  }
  return 0;
}

float Glucose_Reading(unsigned int val) {
  int bitmask = 0x0FFF;
  return ((val & bitmask) / 8.5);
}

String Build_Packet(float glucose) {

  nRawRecord msg;
  //prepare the message
  msg.size = sizeof(msg);
  msg.cmd_code = 0x00;
  msg.raw = glucose*1000; // raw_value
  msg.filtered = msg.raw;
  msg.dex_battery = batteryPcnt;  // simulate good dexcom transmitter battery
  msg.my_battery = readVcc();
  msg.dex_src_id = 0xA5B1AE;
  msg.delay = 5000;
  msg.function = 0x01;

  String packet = "";
  packet+=String(sizeof(msg));
  packet+=String(0x00);
  packet+=String(glucose*1000);
  packet+=String(msg.raw);
  packet+=String(batteryPcnt);
  packet+=String(readVcc());
  packet+=String(0xA5B1AE);
  packet+=String(5000);
  packet+=String(0x01);

  if ((packet.substring(0,1) != "0"))
  {
    send_data( (unsigned char *)&msg, msg.size);
    delay(1000);
  }
  else
  {
    if (bdebug) {
      Serial.println("");
      Serial.print("Packet not sent! Maybe a corrupt scan or an expired sensor.");
      Serial.println("");
    }
    delay(1000);
  }

  return packet;

  // Let's build a String which xDrip accepts as a BTWixel packet
  /*
      unsigned long raw = glucose*1000; // raw_value
   String packet = "";
   packet = String(raw);
   packet += ' ';
   packet += "216";
   packet += ' ';
   packet += String(batteryPcnt);
   packet += ' ';
   packet += String(sensorMinutesElapse);
   Serial.println("");
   Serial.print("Glucose level: ");
   Serial.print(glucose);
   Serial.println("");
   Serial.print("15 minutes-trend: ");
   Serial.println("");
   for (int i=0; i<16; i++)
   {
   Serial.print(trend[i]);
   Serial.println("");
   }
   Serial.print("Battery level: ");
   Serial.print(batteryPcnt);
   Serial.print("%");
   Serial.println("");
   Serial.print("Battery mVolts: ");
   Serial.print(batteryMv);
   Serial.print("mV");
   Serial.println("");
   Serial.print("Sensor lifetime: ");
   Serial.print(sensorMinutesElapse);
   Serial.print(" minutes elapsed");
   Serial.println("");
   return packet;*/
}

// send data to BLE
void send_data(unsigned char *msg, unsigned char len)
{
  unsigned char i = 0;

  for ( i = 0; i < len; i++ )
    ble_Serial.write(msg[i]);

  // wait up to 40 chars (@9600)
  delay(40);
  for ( i = 0 ; i < len ; i++ ) {
    if (bdebug) Serial.print(msg[i], HEX);
  }
}

void Send_Packet(String packet) {
  /*   if ((packet.substring(0,1) != "0"))
   {
   Serial.println("");
   Serial.print("xDrip packet: ");
   for (int i = 0; i < packet.length(); i++ ) {
   ble_Serial.write(packet[i]);
   Serial.write(packet[i]);
   Serial.write(";");
   }
   Serial.println("");
   Serial.println("");**************************************************
   Serial.print("xDrip packet: ");
   Serial.print(packet);
   Serial.println("");
   ble_Serial.print(packet);*****************************************
   delay(1000);
   }
   else
   {
   Serial.println("");
   Serial.print("Packet not sent! Maybe a corrupt scan or an expired sensor.");
   Serial.println("");
   delay(1000);
   }*/
}

int readVcc() {
  // Read 1.1V reference against AVcc
  // set the reference to Vcc and the measurement to the internal 1.1V reference
#if defined(__AVR_ATmega32U4__) || defined(__AVR_ATmega1280__) || defined(__AVR_ATmega2560__)
  ADMUX = _BV(REFS0) | _BV(MUX4) | _BV(MUX3) | _BV(MUX2) | _BV(MUX1);
#elif defined (__AVR_ATtiny24__) || defined(__AVR_ATtiny44__) || defined(__AVR_ATtiny84__)
  ADMUX = _BV(MUX5) | _BV(MUX0);
#elif defined (__AVR_ATtiny25__) || defined(__AVR_ATtiny45__) || defined(__AVR_ATtiny85__)
  ADMUX = _BV(MUX3) | _BV(MUX2);
#else
  ADMUX = _BV(REFS0) | _BV(MUX3) | _BV(MUX2) | _BV(MUX1);
#endif  

  delay(2); // Wait for Vref to settle
  ADCSRA |= _BV(ADSC); // Start conversion
  while (bit_is_set(ADCSRA,ADSC)); // measuring

  uint8_t low  = ADCL; // must read ADCL first - it then locks ADCH  
  uint8_t high = ADCH; // unlocks both

  batteryMv = (high<<8) | low;

  batteryMv = 1125300L / batteryMv; // Calculate Vcc (in mV); 1125300 = 1.1*1023*1000
  int batteryLevel = min(map(batteryMv, MIN_V, MAX_V, 0, 100), 100); // Convert voltage to percentage
  return batteryLevel;
}

void goToSleep(const byte interval, int time) {

  SPI.end();
  digitalWrite(MOSIPin, LOW);
  digitalWrite(SCKPin, LOW);
  digitalWrite(NFCPin1, LOW); // Turn off all power sources completely
  digitalWrite(NFCPin2, LOW); // for maximum power save on BM019.
  digitalWrite(NFCPin3, LOW);
  digitalWrite(IRQPin, LOW);
  digitalWrite(5, LOW);
  digitalWrite(6, LOW);
  digitalWrite(BLEPin, LOW);
  digitalWrite(BLEState, LOW);

  for (int i=0; i<time; i++) {
    MCUSR = 0;                         
    WDTCSR |= 0b00011000;               
    WDTCSR =  0b01000000 | interval;
    set_sleep_mode (SLEEP_MODE_PWR_DOWN);
    sleep_enable();
    sleep_cpu();           
  } 
}
ISR(WDT_vect) 
{
  wdt_disable(); 
}

void wakeUp() {

  sleep_disable();
  power_all_enable();
  wdt_reset();
  restartBLE();

  for (int i=0; ( (i < MAX_BLE_WAIT) && (digitalRead(BLEState) != HIGH) ); i++)
  {
    delay(1000);
    if (bdebug) Serial.print("Waiting for BLE connection ...");
    if (bdebug) Serial.println("");
  }    
  digitalWrite(NFCPin1, HIGH);
  digitalWrite(NFCPin2, HIGH);
  digitalWrite(NFCPin3, HIGH);
  digitalWrite(IRQPin, HIGH);
  SPI.begin();
  SPI.setDataMode(SPI_MODE0);
  SPI.setBitOrder(MSBFIRST);
  SPI.setClockDivider(SPI_CLOCK_DIV32);
  delay(10);                      
  digitalWrite(IRQPin, LOW);       
  delayMicroseconds(100);         
  digitalWrite(IRQPin, HIGH);      
  delay(10);
  digitalWrite(IRQPin, LOW);

  NFCReady = 0;
}
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
void loop() {

  batteryPcnt = readVcc();
  if (batteryPcnt < 1)
    batteryLow = 1;
  while (batteryLow == 1)
  {
    lowBatterySleep();
    batteryPcnt = readVcc();
    if (batteryPcnt > 10)
    {
      batteryLow = 0;
      wakeUp();
      delay(200);
    }
  }
  if (NFCReady == 0)
  {
    SetProtocol_Command(); // ISO 15693 settings
    delay(100);
  }
  else if (NFCReady == 1)
  {
    for (int i=0; i<5; i++) {
      Inventory_Command(); // sensor in range?
      if (NFCReady == 2)
        break;
      delay(1000);
    }
    if (NFCReady == 1) {
      goToSleep (0b100001, SLEEP_TIME);
      wakeUp();
      delay(100); 
    }
  }
  else
  {
    String xdripPacket = Build_Packet(Read_Memory());
    //Send_Packet(xdripPacket);
    goToSleep (0b100001, SLEEP_TIME);
    wakeUp();
    delay(200);
  }
}

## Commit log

2020-06-04 Diagram corrected to save power
2020-06-10 Delete Schematic_2nd Version FreestyleLibre reader_2020-06-04_18-17-28.pdf
    Errors Found
